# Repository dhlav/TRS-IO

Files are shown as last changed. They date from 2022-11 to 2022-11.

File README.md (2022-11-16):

# TRS-IO

TRS-IO gives a TRS-80 Model 1/III online capabilities and provides
access to a variety of services. TRS-IO currently features the
following capabilities:

1. Access to the <a href="https://retrostore.org">RetroStore</a>
2. <a href="http://frehd.com">FreHD</a> emulation
3. Access to files mounted on a SMB share or located on a micro-SD card
4. Access to remote servers via TCP
5. Virtual printer support

The TRS-IO versions for the Model 1 have some additional features that
are explained below. The following sections give an overview of TRS-IO as well as setup
instructions. This Github repository contains the complete source code
as well as the KiCad schematics for the PCB (Printed Circuit Board).
For the following descriptions it is assumed that an assembled TRS-IO
card is available.

### Overview

The figure below depicts the overall architecture. The TRS-80 machine
is connected to TRS-IO via the I/O Bus.  TRS-IO has a WiFi module that
connects to the local WiFi router. This allows TRS-IO to connect to
the Internet and access various services. Note that TRS-IO can only
connect to a 2.4 GHz WiFi network.



### Prerequisites

TRS-IO requires a TRS-80 Model III with 48kB of RAM or a Model 1 with 16kB of RAM.
Floppy disk drives or a cassette tape are not required.

### Feature list

TRS-IO support
TRS-IO comes in three different versions:

* TRS-IO for the Model III
* TRS-IO for the Model I using a builtin 32kB SRAM
* TRS-IO for the Model I using an FPGA

In the following, each of the versions is explained in detail.

### TRS-IO for the Model III

The following figure shows the top view of the TRS-IO card for the Model III:



1. Power supply via a micro-USB connector
2. Multi-color status LED
3. Status button
4. TRS-80 I/O bus connector
5. Micro-SD card reader
6. Disable FreHD jumper

The TRS-IO card needs to be connected to the TRS-80 Model III's I/O
Bus via a 50-pin ribbon cable (4). Furthermore, the TRS-IO card needs
a separate power supply via a standard 5V USB charger. The micro-USB
connector (1) plugs into the side of the TRS-IO card. The push button
(3) and the multi-color status LED (2) will be explained in the
configuration section.

### TRS-IO for the Model 1 (SRAM edition)

The following figure shows the top view of the TRS-IO card for the Model 1:



1. Power supply via a micro-USB connector
2. Multi-color status LED
3. Status button
4. TRS-80 I/O bus connector
5. Micro-SD card reader

The TRS-IO version for the Model 1 is almost identical to the Model III.
One difference is the I/O bus connector (4) is compatible with the 40-pin
expansion interface of the Model 1. There are several additional features
for the Model 1 version that are not relevant to the Model III version:

* A 32kB SRAM chip for a total of 48kB of total RAM.
* 25ms heartbeat timer to trigger the realtime clock.
* FreHD auto-boot for an unmodified M1.

### TRS-IO for the Model 1 (FPGA edition)

The TRS-IO project features a second version for the Model 1 that makes use
of an FGPA (Field Programmable Gate Array). Using an FPGA allows for some
advanced features not possible with the SRAM edition of TRS-IO. The following
figure shows the top view of the FPGA version for the Model 1:



1. Power supply via a micro-USB connector
2. Multi-color status LED
3. Status button
4. TRS-80 I/O bus connector
5. Micro-SD card reader
6. N/A
7. VGA connector
8. A15/VU configuration jumpers

This version of TRS-IO offers all the features of the SRAM edition of TRS-IO
as outlined in the previous section. Additionally, the FPGA edition also
offers a VGA connector (7) that can be used instead of a CRT monitor. This version
of TRS-IO also emlates the LE18 graphics cards. The color of the VGA signal can
be set to white (X=0), green (X=1), and amber (X=2) via the following OUT statements:

```OUT 31,0:OUT 31,5:OUT 31,X```

There are two configuation jumpers (8):
With the VU jumper, the ESP also powers the FPGA. When using this jumper, the FPGA
SHOULD NOT be powered via its own micro-USB connector; power should only be supplied
to the ESP's micro-USB connector (1). The A15 jumper regulates
the address range the FPGA responds to. Without the A15 jumper, the FPGA only
responds to memory read/write requests for the upper 32 kB (essentially mimicking the
upper RAM of the SRAM edition). With the A15 jumper, the FPGA will respond to the
complete 64kB address space of the Z80. This requires a modified Model 1 as the FPGA also
responds to ROM read requests.

### Configuring TRS-IO

The core of the TRS-IO card is an ESP32 microcontroller that features
a WiFi module that is used to connect to a WiFi router. After
physically connecting the TRS-IO card to a TRS-80 Model 1/III as
explained in the previous sections, the WiFi module on the ESP32
microcontroller first needs to be be configured with the credentials
of the local WiFi network.

While in setup mode, the TRS-IO's status LED will continuously blink
in white to indicate that it has not yet been configured. While in
that mode, TRS-IO will create an open access point called
"TRS-IO". Use a laptop to connect to this WiFi network and then use a
browser to visit URL <a
href="http://trs-io.local">trs-io.local</a>. The following web page
should appear in the browser:

<img src="doc/trs-io-web-ui.png" width="50%" />

Some hosts do not correctly handle mDNS that is used to resolve <a
href="http://trs-io.local">trs-io.local</a>. In that case, visit the
IP address <a href="http://192.168.4.1">192.168.4.1</a> instead.
The web interface shown above can be used to configure SSID and password of the WiFi
network that TRS-IO should connect to, the local timezone as well as
the credentials of a SMB share. For open networks leave the WiFi
password field empty. Note that TRS-IO cannot connect to WiFi networks
that use a capture portal. The timezone as well as the SMB share are
not required but will result in limited functionality.

Once all the information is provided, click on submit to upload the
parameters. TRS-IO will automatically reboot and try to connect to the
specified WiFi network. If successful, the LED will turn green for a
few seconds. If the credentials are wrong or if the specified WiFi
network is not accessible, the LED light will turn permanently red.

Note that TRS-IO will store all parameters in its local flash memory,
so the setup only needs to be performed once. Once TRS-IO is connected
to a WiFi router, it should still be possible to access URL <a
href="http://trs-io.local">trs-io.local</a> from a browser on the same
WiFi network. If mDNS is not supported by the host, the following BASIC
program can be used to determine TRS-IO's local IP address that was
assigned by the router:

```
10 OUT 236,16
20 OUT31,0:OUT31,4
30 C=INP(31):IF C=0 THEN END
40 PRINT CHR$(C);
50 GOTO 30
```

The web interface will also display two icons to indicate the status
of the SMB share and the micro-SD card (see screenshot above). Green
icons indicate that TRS-IO has access. Red icons indicate an error.
In that case, hovering the mouse over the red icon will display the
error message. It should be noted that TRS-IO needs to be rebooted
whenever a micro-SD card is inserted or ejected.

Pushing the status button will make the LED flash twice. The first time for
the WiFi status (green: WiFi connected; red: WiFi not connected) and a
second time for the SMB status (green: connected to SMB share; red:
not connected to SMB share). With proper configuration parameters, the
LED should flash green twice. Holding down the push button for more
than three seconds will erase all configuration parameters and place
TRS-IO back into setup mode (status LED flashing white). This
might be necessary if TRS-IO is moved to a different WiFi network.

The status LED indicates the state of TRS-IO:

* Blinking white: TRS-IO is not configured. It will create an open WiFi access point named "TRS-IO"
* Solid green: when TRS-IO has been configured with WiFi credentials and TRS-IO was able
  to connect to the WiFi network, the status LED will light in solid green for several seconds.
* Solid red: TRS-IO was configured with WiFi credentials but it was not possible to connect to the specified
  network. The reason could be wrong credentials or the specified network is itself offline. The push button can be
  used to reset TRS-IO into setup mode in case different credentials need to be provided.
* Solid blue: TRS-IO performs an OTA (Over-the-Air) update. TRS-IO will automatically detect
  newer firmware versions and will download and install the new firmware. The status LED will light solid blue during
  this process.
* Off: the status LED will be off during regular operations when TRS-IO is connected to the specified
  WiFi network and ready to accept commands from the TRS-80 Model III.
 
### FreHD

TRS-IO is compatible with the popular <a
href="http://frehd.com">FreHD</a> hard disk emulator. The FreHD disk
images can either be stored on a SMB share or on a micro-SD card.
If a micro-SD card is inserted, it will take precedence over
a mounted SMB share. Once TRS-IO is configured to access a SMB share,
simply copy the required files such as <a
href="http://members.iinet.net.au/~ianmav/trs80/downloads.htm">FREHD.ROM</a>
to the SMB share. Alternatively, the disk images can be transferred
to the micro-SD card. The IMPORT/EXPORT utilities will access files on the
SMB share or micro-SD card respectively.

### Virtual Printer Interface

TRS-IO support a virtual printer interface. Visiting <a
href="http://trs-io.local/printer">trs-io.local/printer</a> from a browser
will open the printer interface. Any printer output from the M1/MIII will
be displayed in the printer interface. If the host cannot resolve the mDNS name
trs-io.local, the above BASIC program can be used to determine the TRS-80's
IP address.

 ### Launching the native RetroStore Client

The <a href="https://retrostore.org">RetroStore</a> hosts applications
for the Tandy Radio Shack vintage computers and allows to seamlessly
download and run these applications without the need of cassettes or
floppy disks. TRS-IO acts as a gateway to the <a
href="https://retrostore.org">RetroStore</a>. This requires to run a
program on the TRS-80 that interfaces with TRS-IO. This program is
available as a regular <a
href="https://github.com/apuder/TRS-IO/blob/master/src/esp/components/retrostore/rsclient.cmd">CMD</a>
executable.  For TRS-80 machines with attached physical floppy disks,
this CMD executable can be copied to a floppy disk and launched the
usual way. For TRS-80 machines that have neither floppy disk drives
nor cassette drives, it is also possible to bootstrap the native
client via the following short BASIC program:
 
 ```BASIC
 10 OUT236,16
 20 OUT31,3
 30 OUT31,1
 40 N=INP(31)+256*INP(31)
 50 FOR X=1 TO N:POKE20735+X,INP(31):NEXT
 RUN
 SYSTEM
 *? /20736
 ```
 
The above BASIC program will download the CMD executable from TRS-IO
and launch the native client.  Note that this procedure needs to be
repeated every time the TRS-80 is turned on.
 
### Using the native RetroStore Client

After successfully launching the native RetroStore client, the monitor
of the TRS-80 should look like this:
 

 
The screenshot above shows the main menu of the native RetroStore
client. The arrow indicates the currently selected menu item.  The up
and down cursor keys can be used to move between the various menu
items. Hitting the ENTER key will activate the currently selected
menu item. Pressing CLEAR or BREAK in sub-menus will return to the
previous menu.
 
Keyboard controls:
 
 * Cursor up/down: toggle menu selection
 * ENTER: select current menu selection
 * BREAK/CLEAR: exit to previous screen

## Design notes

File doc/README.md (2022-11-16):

### TRS-IO Documentation

[TCP/IP](tcp_ip.md) - details about the tsrnic TCP/IP API implemented by TRS-IO

[BOM](build.md) - a detailed list of all components you need to build a TRS-IO board

[Old Board Fix](rs_fix.md) - bodge wire updates to make the original RS board compatible with TRS-IO

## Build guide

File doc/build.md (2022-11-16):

#### TRS-IO - Circuit Board Bill of Materials

|Qty|Ref|Digikey Part#|Manuf Part #|Description|
|:---|:---|:---|:---|:---|
|1|U1||ESP32 MODULE|Refer to Supported ESP32 Modules
|1|U3|[ATF16V8B-15PU-ND](https://www.digikey.com/product-detail/en/microchip-technology/ATF16V8B-15PU/ATF16V8B-15PU-ND/1118926)|ATF16V8B-15PU|IC PLD 8MC 15NS 20DIP
|2|U2,U4|[296-8503-5-ND](https://www.digikey.com/product-detail/en/texas-instruments/SN74LVC245AN/296-8503-5-ND/377483)|SN74LVC245AN|IC TXRX NON-INVERT 3.6V 20DIP
|3|Q1,Q2,Q3|[2N7000-G-ND](https://www.digikey.com/product-detail/en/microchip-technology/2N7000-G/2N7000-G-ND/4902350)|2N7000-G|MOSFET N-CH 60V 0.2A TO92-3
|1|D1|[1830-1014-ND](https://www.digikey.com/product-detail/en/inolux/HV-5RGB60/1830-1014-ND/7604616)|HV-5RGB60|LED RGB DIFFUSED 5MM T/H
|1|SW1|[450-1650-ND](https://www.digikey.com/product-detail/en/te-connectivity-alcoswitch-switches/1825910-6/450-1650-ND/1632536)|1825910-6|SWITCH TACTILE SPST-NO 0.05A 24V
|1|SW2||1825910-6|SWITCH TACTILE RIGHT-ANGLE SPST-NO 0.05A 24V
|3|U2,U3,U4|[ED3054-5-ND](https://www.digikey.com/product-detail/en/on-shore-technology-inc/ED20DT/ED3054-5-ND/4147598)|ED20DT|CONN IC DIP SOCKET 20POS TIN
|1|J1|[ED10530-ND](https://www.digikey.com/product-detail/en/on-shore-technology-inc/302-S501/ED10530-ND/2794241)|302-S501|CONN HEADER VERT 50POS 2.54MM
|1||[HDR100IMP40F-G-V-TH-ND](https://www.digikey.com/product-detail/en/chip-quik-inc/HDR100IMP40F-G-V-TH/HDR100IMP40F-G-V-TH-ND/5978200)|HDR100IMP40F-G-V-TH|SIL HDR 40POS 0.1 GOLD PCB
|4|C1,C2,C3,C4|[490-8809-ND](https://www.digikey.com/short/pvj15w)|RDER71E104K0P1H03B|CAP CER 0.1UF 25V X7R RADIAL
|3|R1,R2,R3|||100R 0.25W
|1|R4|||4K7 0.25W

#### Supported ESP32 Modules:
The TRS-IO board supports two commonly available ESP32 modules.

* 38 Pin Module commonly branded as NodeMCU or HiLetGo



* 30 Pin Module commonly branded as DEVKITV1



The pinout and spacing of the two modules differs.  Unless you plan to test your board with both modules, install 15 pin SIL sockets in 1st and 3rd positons for the 30 Pin Module or 19 pin SIL sockets in the 2nd and 4th positions for the 38 Pin Module.

Correct orientation of the modules is shown below:

* 38 Pin Module commonly branded as NodeMCU or HiLetGo



* 30 Pin Module commonly branded as DEVKITV1



#### Notes:
* The switch can be installed in either SW1 or SW2.  SW2 is recommended when assembling the board for installation in a case.
* The LED can be installed in either D1 or J4.  J4 is recommended when assembling the board for installation in a case.  Do not install an LED in both D1 and J4.
* R1,R2 and R3 are current limiting resistors for the LED.  The values are not critical and may require adjustment for some LED.
* The J5 header can be installed and jumpered to disable the internal FreHD emulation when an external FreHD is connected to the expansion connector.  J5 can be omitted if an external FreHD is not used.
* R4 is a pullup for the ESP32 FreHD Inhibit signal. This must always be installed even J5 is not.  Value is not critical.  Anything between 4K7 and 10K will work.
* 5V can be connected to J5 as an alternative to powering ESP32 from USB.  This is recommended when assembling the board for installation in a case.

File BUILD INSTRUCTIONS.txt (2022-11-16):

#TRS-IO - Build Instructions
#OS: Debian 11

#Install Prerequisites:
#Packages for Espressif
sudo apt-get -y install git wget flex bison gperf python3 python3-pip python3-setuptools cmake ninja-build ccache libffi-dev libssl-dev dfu-util libusb-1.0-0

#Packages for TRS-IO
sudo apt-get -y install z80asm sdcc sdcc-libraries

# Some Fixes for linking libraries thats needed by TRS-IO
sudo mkdir -p /lib/z80/
sudo ln -s /usr/share/sdcc/lib/z80/z80.lib /lib/z80/z80.lib

#Python3 as default:
sudo apt-get install python3 python3-pip python3-setuptools
sudo ln -s /usr/bin/python3 /usr/bin/python

#ESP-IDF (Blanket Install Everything):
mkdir -p ~/esp
cd ~/esp
git clone -b v4.2 --recursive https://github.com/espressif/esp-idf.git
cd ~/esp/esp-idf
export IDF_GITHUB_ASSETS="dl.espressif.com/github_assets"
./install.sh
. $HOME/esp/esp-idf/export.sh

#CHECK OUT TRS-IO
cd ~/esp
git clone --recursive https://github.com/dhlav/TRS-IO.git
cd TRS-IO
make all

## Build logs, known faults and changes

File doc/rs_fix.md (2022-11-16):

### RetroStoreCard Wiring Fix

If you have the original RetroStoreCard it can be made compatible with TRS-IO by adding a number of bodge wires.



The original RetroStoreCard looks like the one above.  If you have one of these, then you need to add the following wire connections to bring it up to spec with TRS-IO.



#### Wire Table

|From |To|
|:---|:---|
|ESP 23| IC3 15
|ESP 24| IC3 13
|ESP 25| IC3 14
|ESP 26| IC3 11
|ESP 27| IC3 12
|IC1 6| IC3 5
|IC1 7| IC3 7
|IC1 8| IC3 8
|IC1 9| IC3 9
|IC1 16| IC3 5

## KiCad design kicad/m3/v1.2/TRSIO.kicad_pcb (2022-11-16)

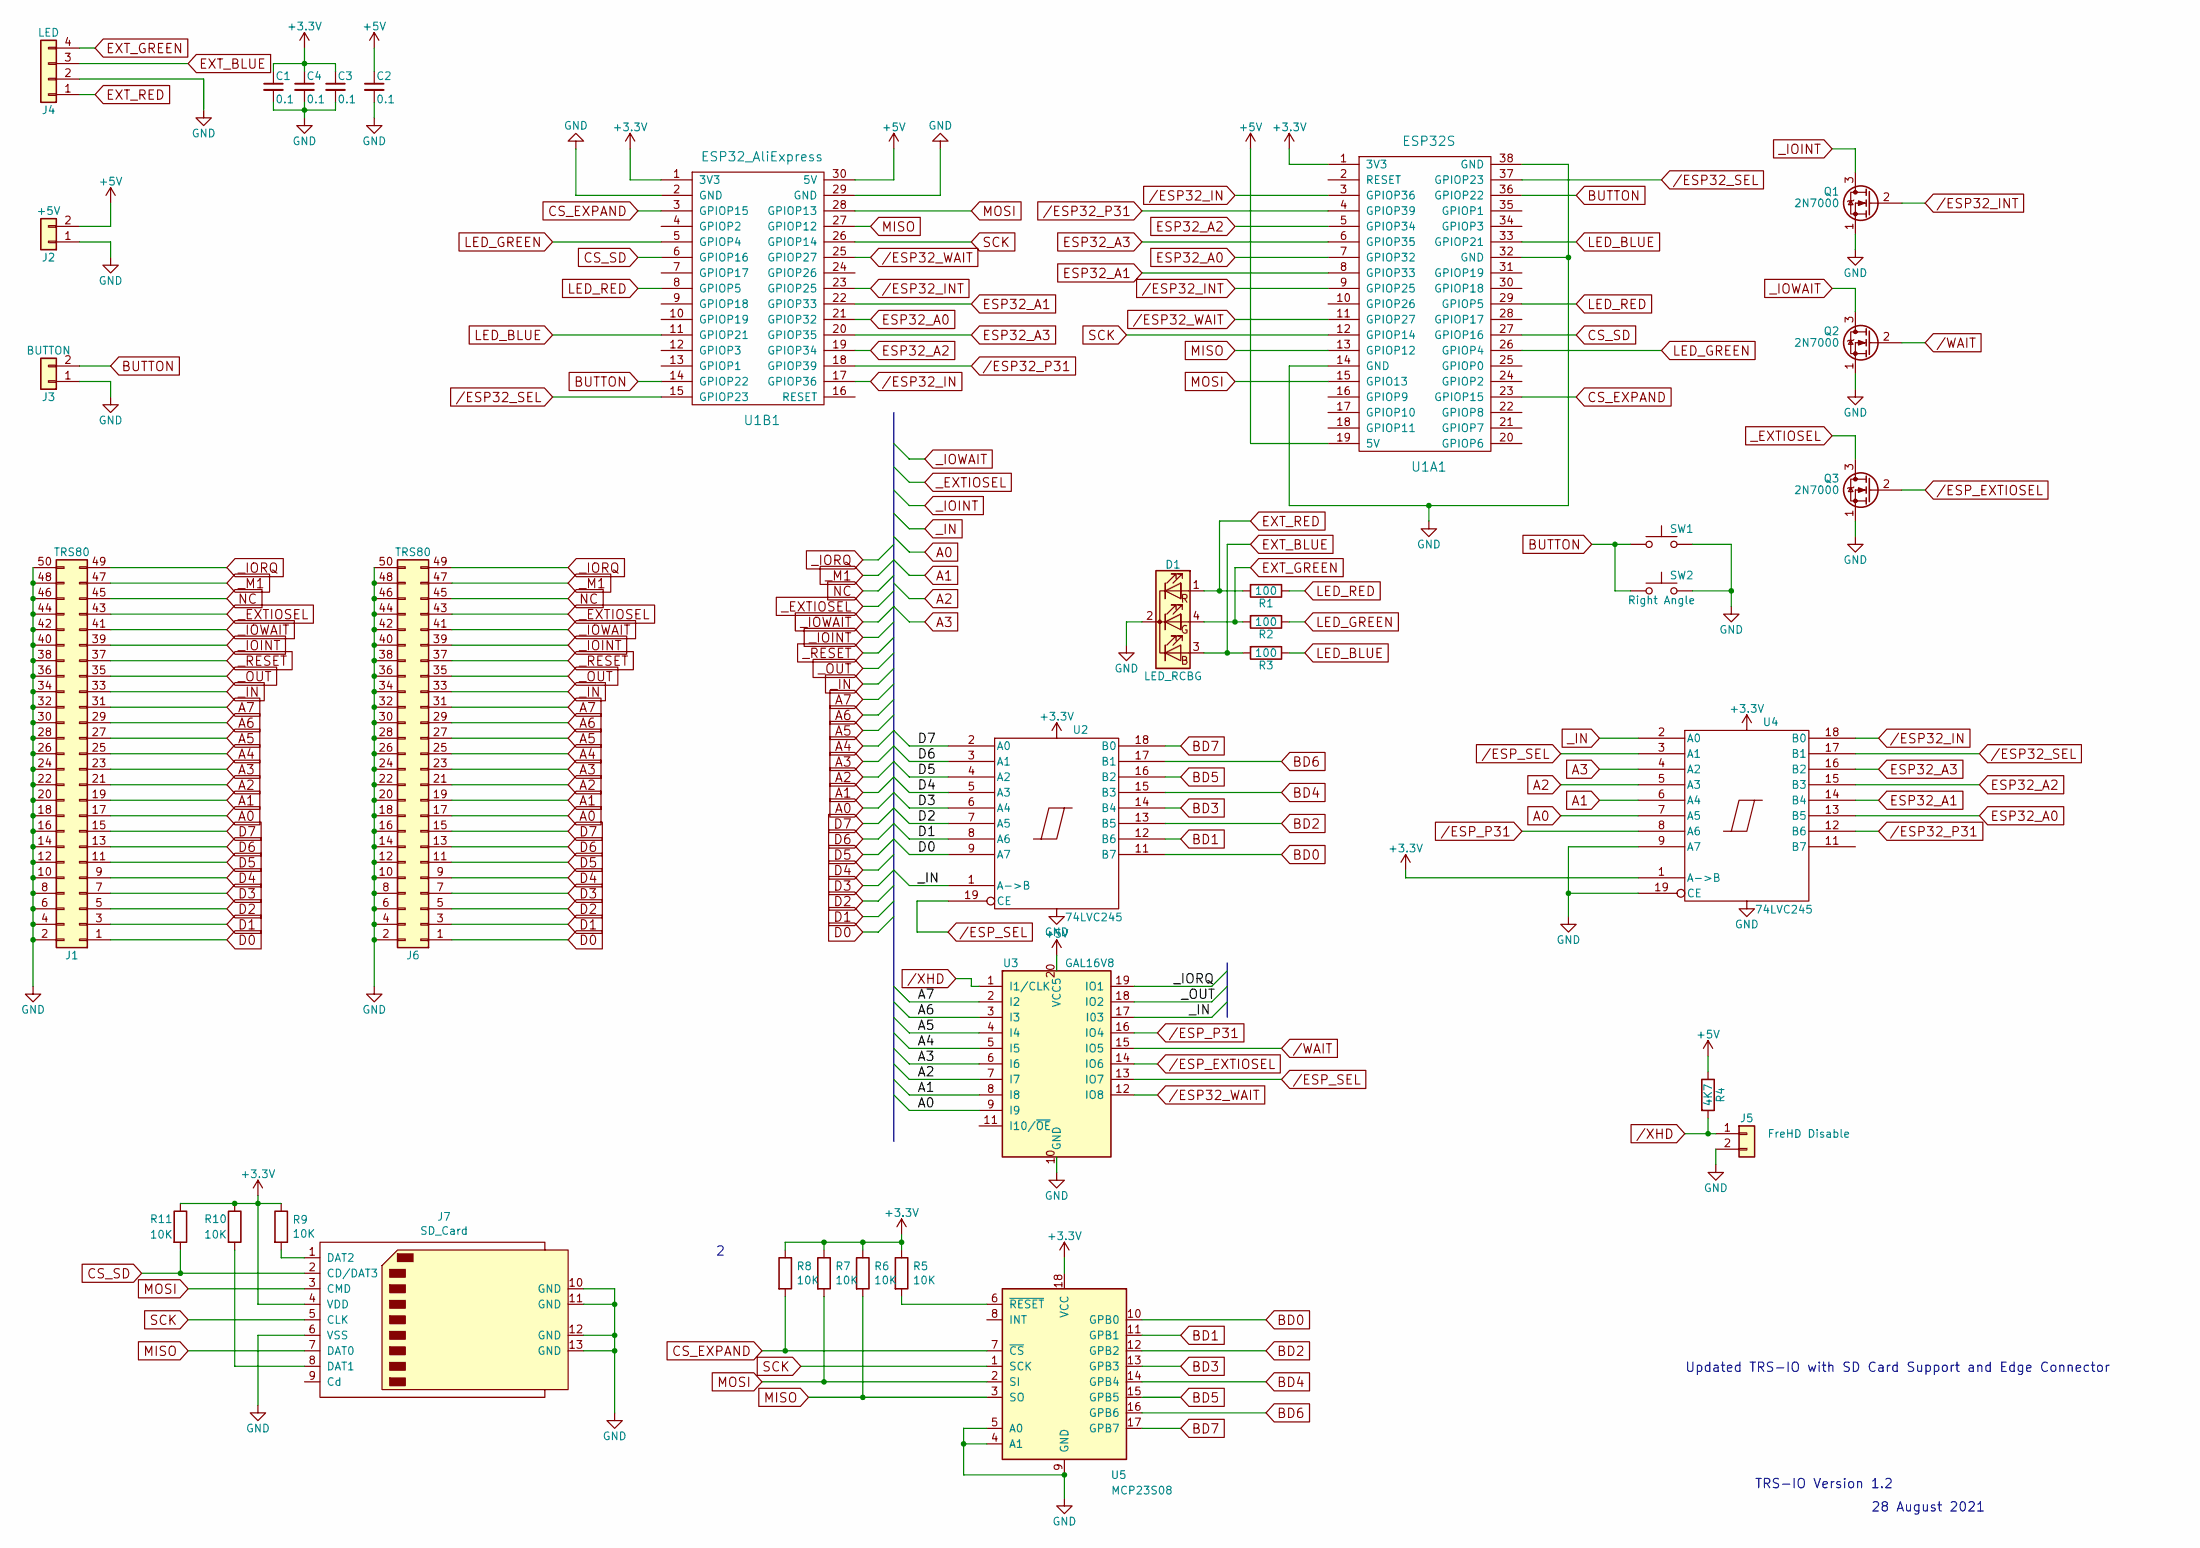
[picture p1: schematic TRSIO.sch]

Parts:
C1, C2, C3, C4: 0.1; C_Disc_D3.0mm_W2.0mm_P2.50mm
D1: LED_RCBG; LED_D5.0mm-4
J1: TRS80; Pin_Header_Straight_2x25_Pitch2.54mm
J2: +5V; Pin_Header_Straight_1x02_Pitch2.54mm
J3: BUTTON; Pin_Header_Straight_1x02_Pitch2.54mm
J4: LED; Pin_Header_Straight_1x04_Pitch2.54mm
J5: FreHD Disable; Pin_Header_Straight_1x02_Pitch2.54mm
J6: TRS80; EDGE50
J7: SD_Card; TFP09-2-12B
Q1, Q2, Q3: 2N7000; TO-92_Molded_Narrow
R1, R2, R3: 100; R_Axial_DIN0207_L6.3mm_D2.5mm_P7.62mm_Horizontal
R4: 4K7; R_Axial_DIN0207_L6.3mm_D2.5mm_P7.62mm_Horizontal
R5, R6, R7, R8, R9, R10, R11: 10K; R_Axial_DIN0207_L6.3mm_D2.5mm_P7.62mm_Horizontal
SW1: SW_Push; SW_PUSH_6mm_h9.5mm
SW2: Right Angle; SW_Tactile_SPST_Angled_PTS645Vx31-2LFS
U1A1: ESP32S; DIP-38_W22.9mm
U1B1: ESP32_AliExpress; DIP-30_W25.4mm
U2, U4: 74LVC245; DIP-20_W7.62mm
U3: GAL16V8; DIP-20_W7.62mm
U5: MCP23S08; DIP-18_W7.62mm

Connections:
+3V3: C1.1, C3.1, C4.1, J7.4 (VDD), R5.1, R6.1, R7.1, R8.1, R9.1, R10.1, R11.1, U1A1.1 (3V3), U1B1.1 (3V3), U2.20 (VCC), U4.1 (A->B), U4.20 (VCC), U5.18 (VCC)
+5V: C2.1, J2.2, R4.1, U1A1.19 (5V), U1B1.30 (5V), U3.20 (VCC5)
/ESP32_IN: U1A1.3 (GPIOP36), U1B1.17 (GPIOP36), U4.18 (B0)
/ESP32_INT: Q1.2 (G), U1A1.9 (GPIOP25), U1B1.23 (GPIOP25)
/ESP32_P31: U1A1.4 (GPIOP39), U1B1.18 (GPIOP39), U4.12 (B6)
/ESP32_SEL: U1A1.37 (GPIOP23), U1B1.15 (GPIOP23), U4.17 (B1)
/ESP32_WAIT: U1A1.11 (GPIOP27), U1B1.25 (GPIOP27), U3.12 (IO8)
/ESP_EXTIOSEL: Q3.2 (G), U3.14 (IO6)
/ESP_P31: U3.16 (IO4), U4.8 (A6)
/ESP_SEL: U2.19 (CE), U3.13 (IO7), U4.3 (A1)
/WAIT: Q2.2 (G), U3.15 (IO5)
/XHD: J5.1, R4.2, U3.1 (I1/CLK)
A0: J1.17, J6.17, U3.9 (I9), U4.7 (A5)
A1: J1.19, J6.19, U3.8 (I8), U4.6 (A4)
A2: J1.21, J6.21, U3.7 (I7), U4.5 (A3)
A3: J1.23, J6.23, U3.6 (I6), U4.4 (A2)
A4: J1.25, J6.25, U3.5 (I5)
A5: J1.27, J6.27, U3.4 (I4)
A6: J1.29, J6.29, U3.3 (I3)
A7: J1.31, J6.31, U3.2 (I2)
BD0: U2.11 (B7), U5.10 (GPB0)
BD1: U2.12 (B6), U5.11 (GPB1)
BD2: U2.13 (B5), U5.12 (GPB2)
BD3: U2.14 (B4), U5.13 (GPB3)
BD4: U2.15 (B3), U5.14 (GPB4)
BD5: U2.16 (B2), U5.15 (GPB5)
BD6: U2.17 (B1), U5.16 (GPB6)
BD7: U2.18 (B0), U5.17 (GPB7)
BUTTON: J3.2, SW1.1, SW2.1, U1A1.36 (GPIOP22), U1B1.14 (GPIOP22)
CS_EXPAND: R8.2, U1A1.23 (GPIOP15), U1B1.3 (GPIOP15), U5.7 (~CS)
CS_SD: J7.2 (CD/DAT3), R11.2, U1A1.27 (GPIOP16), U1B1.6 (GPIOP16)
D0: J1.1, J6.1, U2.9 (A7)
D1: J1.3, J6.3, U2.8 (A6)
D2: J1.5, J6.5, U2.7 (A5)
D3: J1.7, J6.7, U2.6 (A4)
D4: J1.9, J6.9, U2.5 (A3)
D5: J1.11, J6.11, U2.4 (A2)
D6: J1.13, J6.13, U2.3 (A1)
D7: J1.15, J6.15, U2.2 (A0)
ESP32_A0: U1A1.7 (GPIOP32), U1B1.21 (GPIOP32), U4.13 (B5)
ESP32_A1: U1A1.8 (GPIOP33), U1B1.22 (GPIOP33), U4.14 (B4)
ESP32_A2: U1A1.5 (GPIOP34), U1B1.19 (GPIOP34), U4.15 (B3)
ESP32_A3: U1A1.6 (GPIOP35), U1B1.20 (GPIOP35), U4.16 (B2)
EXT_BLUE: D1.3 (BA), J4.3, R3.2
EXT_GREEN: D1.4 (GA), J4.4, R2.2
EXT_RED: D1.1 (RA), J4.1, R1.2
GND: C1.2, C2.2, C3.2, C4.2, D1.2 (K), J1.2, J1.4, J1.6, J1.8, J1.10, J1.12, J1.14, J1.16, J1.18, J1.20, J1.22, J1.24, J1.26, J1.28, J1.30, J1.32, J1.34, J1.36, J1.38, J1.40, J1.42, J1.44, J1.46, J1.48, J1.50, J2.1, J3.1, J4.2, J5.2, J6.2, J6.4, J6.6, J6.8, J6.10, J6.12, J6.14, J6.16, J6.18, J6.20, J6.22, J6.24, J6.26, J6.28, J6.30, J6.32, J6.34, J6.36, J6.38, J6.40, J6.42, J6.44, J6.46, J6.48, J6.50, J7.6 (VSS), J7.10 (GND), J7.11 (GND), J7.12 (GND), J7.13 (GND), Q1.1 (S), Q2.1 (S), Q3.1 (S), SW1.2, SW2.2, U1A1.14 (GND), U1A1.32 (GND), U1A1.38 (GND), U1B1.2 (GND), U1B1.29 (GND), U2.10 (GND), U3.10 (GND), U4.9 (A7), U4.10 (GND), U4.19 (CE), U5.4 (A1), U5.5 (A0), U5.9 (GND)
LED_BLUE: R3.1, U1A1.33 (GPIOP21), U1B1.11 (GPIOP21)
LED_GREEN: R2.1, U1A1.26 (GPIOP4), U1B1.5 (GPIOP4)
LED_RED: R1.1, U1A1.29 (GPIOP5), U1B1.8 (GPIOP5)
MISO: J7.7 (DAT0), R6.2, U1A1.13 (GPIOP12), U1B1.27 (GPIOP12), U5.3 (SO)
MOSI: J7.3 (CMD), R7.2, U1A1.15 (GPIO13), U1B1.28 (GPIOP13), U5.2 (SI)
NC: J1.45, J6.45
unnamed: J7.1 (DAT2), R9.2
unnamed: J7.8 (DAT1), R10.2
unnamed: R5.2, U5.6 (~RESET)
SCK: J7.5 (CLK), U1A1.12 (GPIOP14), U1B1.26 (GPIOP14), U5.1 (SCK)
_EXTIOSEL: J1.43, J6.43, Q3.3 (D)
_IN: J1.33, J6.33, U2.1 (A->B), U3.17 (I03), U4.2 (A0)
_IOINT: J1.39, J6.39, Q1.3 (D)
_IORQ: J1.49, J6.49, U3.19 (IO1)
_IOWAIT: J1.41, J6.41, Q2.3 (D)
_M1: J1.47, J6.47
_OUT: J1.35, J6.35, U3.18 (IO2)
_RESET: J1.37, J6.37

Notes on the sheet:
Updated TRS-IO with SD Card Support and Edge Connector
28 August 2021
TRS-IO Version 1.2

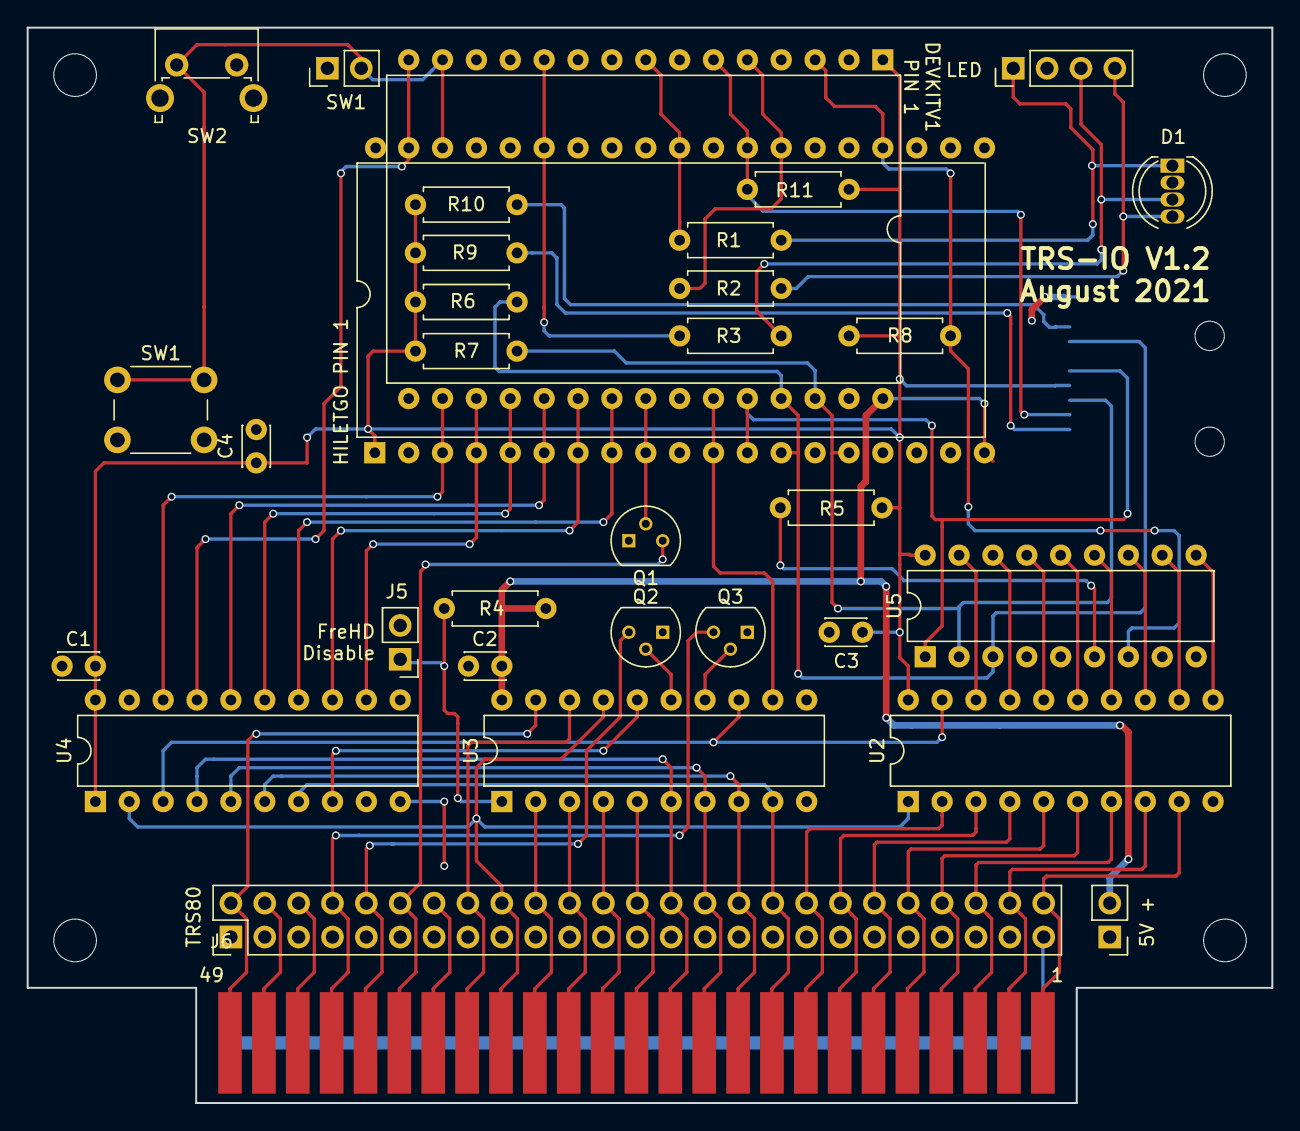
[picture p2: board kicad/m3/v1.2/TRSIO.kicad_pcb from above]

Board: 2 copper layers, 93.3 x 80.6 mm, 34 parts (1 on the bottom side), 65 nets.

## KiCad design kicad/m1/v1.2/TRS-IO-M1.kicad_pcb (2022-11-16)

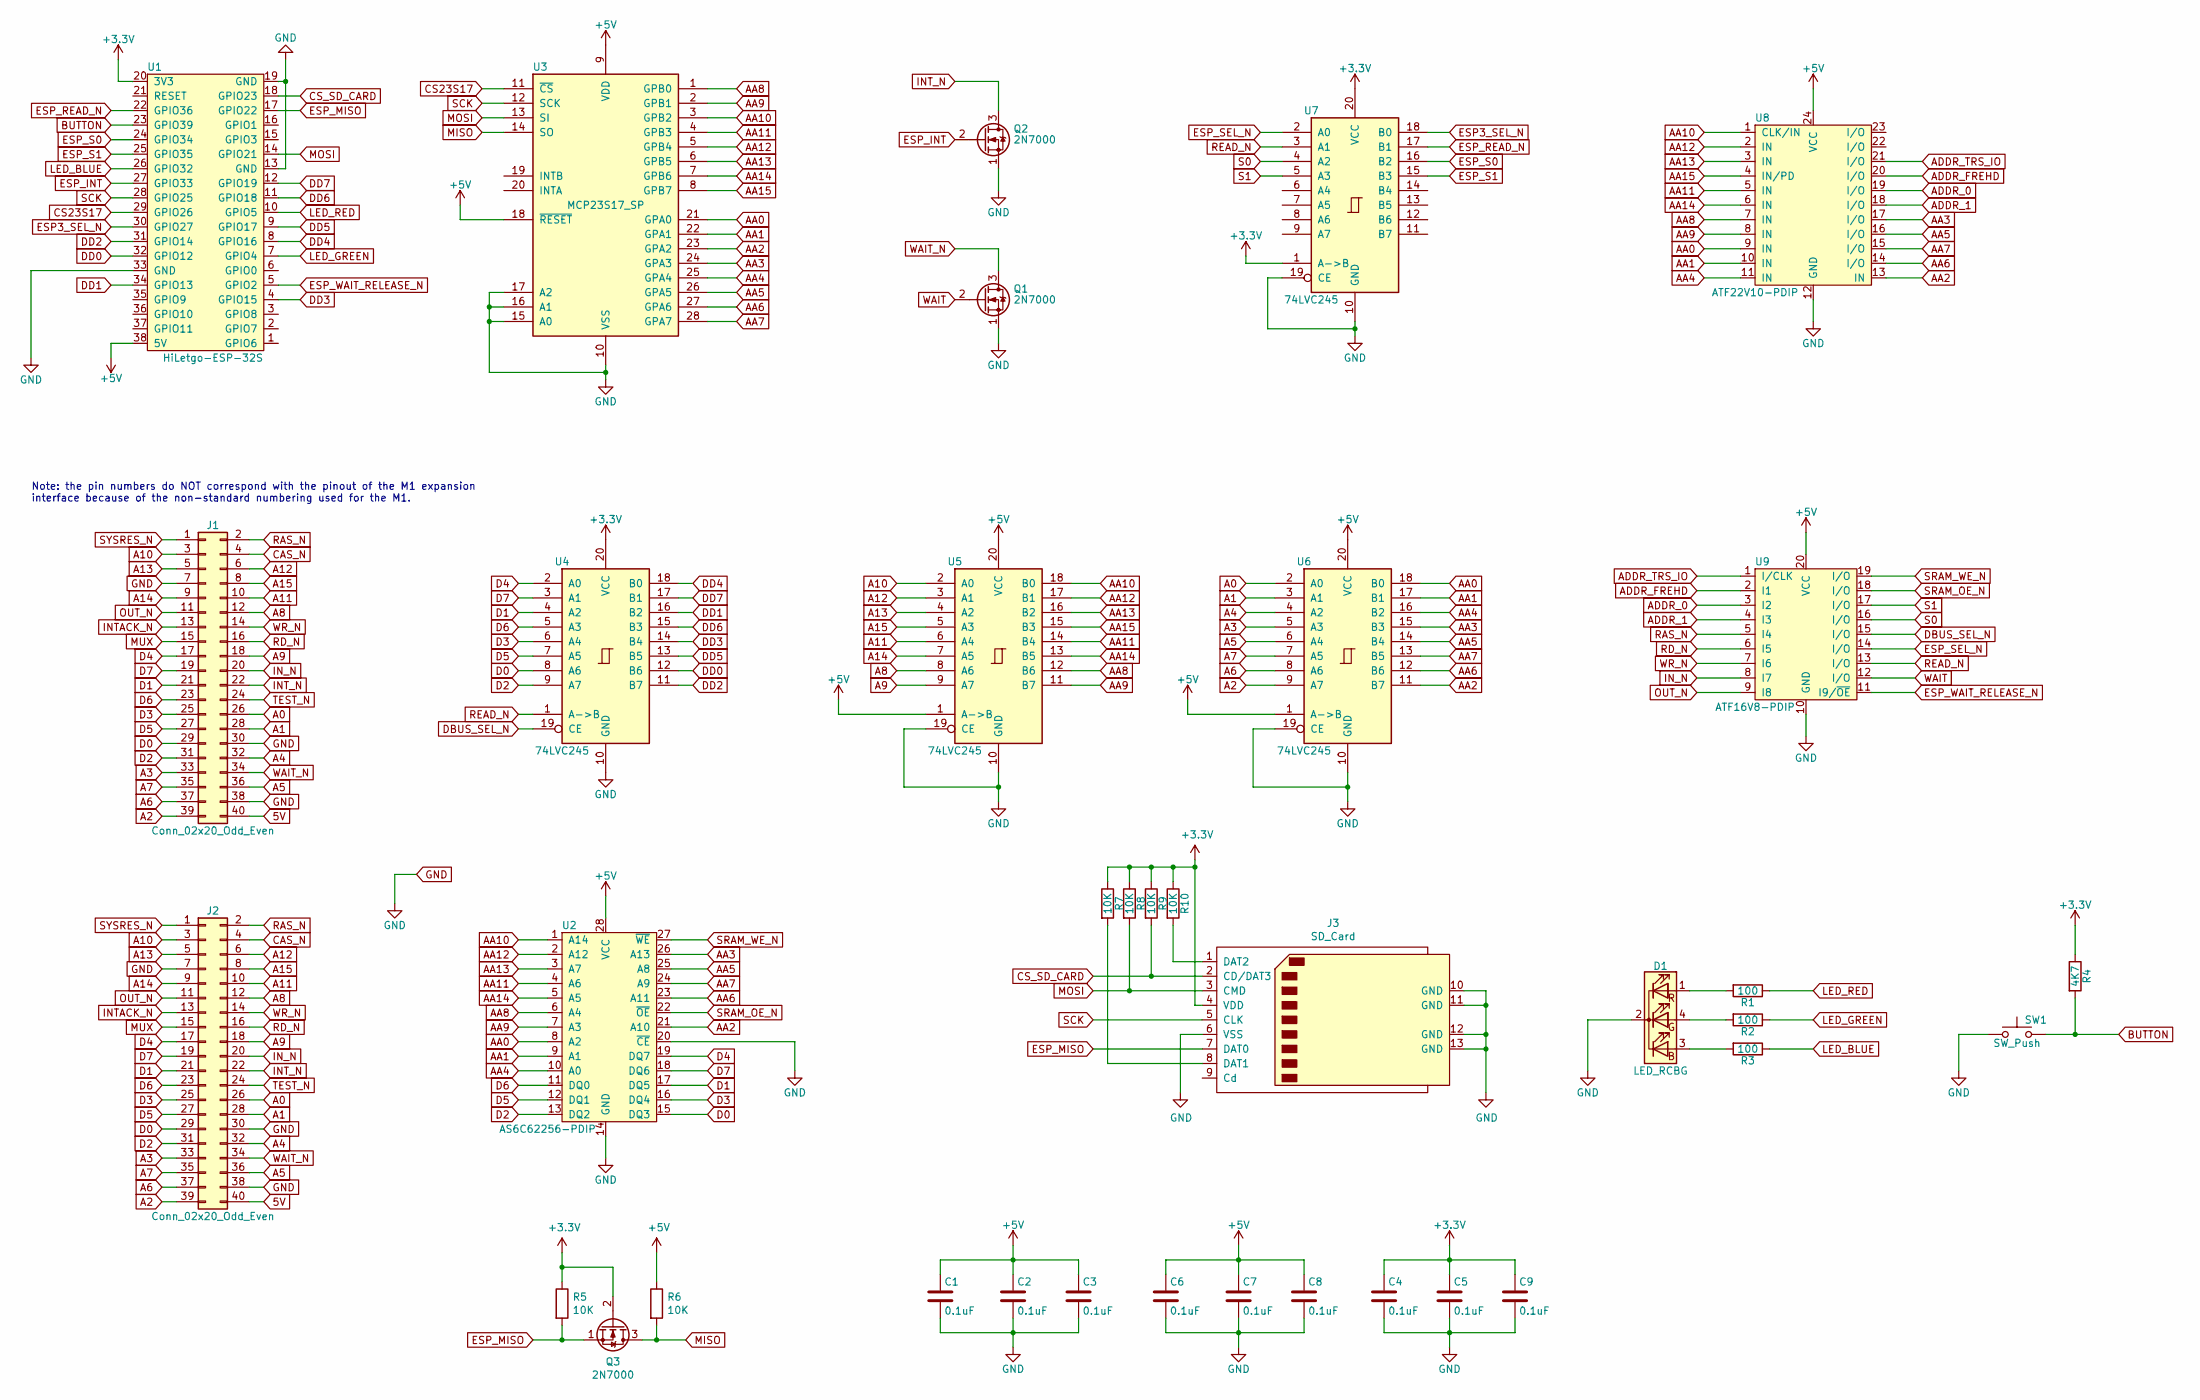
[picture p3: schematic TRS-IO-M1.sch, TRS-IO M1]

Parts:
C1, C2, C3, C4, C5, C6, C7, C8, C9: 0.1uF; C_Disc_D3.0mm_W2.0mm_P2.50mm
D1: LED_RCBG; LED_D5.0mm-4_RGB
J1: Conn_02x20_Odd_Even; PinHeader_2x20_P2.54mm_Vertical
J2: Conn_02x20_Odd_Even; TRSEDGE
J3: SD_Card; TFP09-2-12B
Q1, Q2, Q3: 2N7000; TO-92_Inline
R1, R2, R3: 100; R_Axial_DIN0207_L6.3mm_D2.5mm_P7.62mm_Horizontal
R4: 4K7; R_Axial_DIN0207_L6.3mm_D2.5mm_P7.62mm_Horizontal
R5, R6, R7, R8, R9, R10: 10K; R_Axial_DIN0207_L6.3mm_D2.5mm_P7.62mm_Horizontal
SW1: SW_Push; SW_PUSH_6mm_H9.5mm
U1: HiLetgo-ESP-32S; DIP-38_W22.9mm
U2: AS6C62256-PDIP; DIP-28_W15.24mm
U3: MCP23S17_SP; DIP-28_W7.62mm
U4, U5, U6, U7: 74LVC245; DIP-20_W7.62mm
U8: ATF22V10-PDIP; DIP-24_W7.62mm
U9: ATF16V8-PDIP; DIP-20_W7.62mm

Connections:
5V: J1.40, J2.40
+3V3: C4.1, C5.1, C9.1, J3.4 (VDD), Q3.2 (G), R4.1, R5.1, R7.1, R8.1, R9.1, R10.1, U1.20 (3V3), U4.20 (VCC), U7.1 (A->B), U7.20 (VCC)
+5V: C1.1, C2.1, C3.1, C6.1, C7.1, C8.1, R6.1, U1.38 (5V), U2.28 (VCC), U3.9 (VDD), U3.18 (~RESET~), U5.1 (A->B), U5.20 (VCC), U6.1 (A->B), U6.20 (VCC), U8.24 (VCC), U9.20 (VCC)
A0: J1.26, J2.26, U6.2 (A0)
A1: J1.28, J2.28, U6.3 (A1)
A2: J1.39, J2.39, U6.9 (A7)
A3: J1.33, J2.33, U6.5 (A3)
A4: J1.32, J2.32, U6.4 (A2)
A5: J1.36, J2.36, U6.6 (A4)
A6: J1.37, J2.37, U6.8 (A6)
A7: J1.35, J2.35, U6.7 (A5)
A8: J1.12, J2.12, U5.8 (A6)
A9: J1.18, J2.18, U5.9 (A7)
A10: J1.3, J2.3, U5.2 (A0)
A11: J1.10, J2.10, U5.6 (A4)
A12: J1.6, J2.6, U5.3 (A1)
A13: J1.5, J2.5, U5.4 (A2)
A14: J1.9, J2.9, U5.7 (A5)
A15: J1.8, J2.8, U5.5 (A3)
AA0: U2.8 (A2), U3.21 (GPA0), U6.18 (B0), U8.9 (IN)
AA1: U2.9 (A1), U3.22 (GPA1), U6.17 (B1), U8.10 (IN)
AA2: U2.21 (A10), U3.23 (GPA2), U6.11 (B7), U8.13 (IN)
AA3: U2.26 (A13), U3.24 (GPA3), U6.15 (B3), U8.17 (I/O)
AA4: U2.10 (A0), U3.25 (GPA4), U6.16 (B2), U8.11 (IN)
AA5: U2.25 (A8), U3.26 (GPA5), U6.14 (B4), U8.16 (I/O)
AA6: U2.23 (A11), U3.27 (GPA6), U6.12 (B6), U8.14 (I/O)
AA7: U2.24 (A9), U3.28 (GPA7), U6.13 (B5), U8.15 (I/O)
AA8: U2.6 (A4), U3.1 (GPB0), U5.12 (B6), U8.7 (IN)
AA9: U2.7 (A3), U3.2 (GPB1), U5.11 (B7), U8.8 (IN)
AA10: U2.1 (A14), U3.3 (GPB2), U5.18 (B0), U8.1 (CLK/IN)
AA11: U2.4 (A6), U3.4 (GPB3), U5.14 (B4), U8.5 (IN)
AA12: U2.2 (A12), U3.5 (GPB4), U5.17 (B1), U8.2 (IN)
AA13: U2.3 (A7), U3.6 (GPB5), U5.16 (B2), U8.3 (IN)
AA14: U2.5 (A5), U3.7 (GPB6), U5.13 (B5), U8.6 (IN)
AA15: U3.8 (GPB7), U5.15 (B3), U8.4 (IN/PD)
ADDR_0: U8.19 (I/O), U9.3 (I2)
ADDR_1: U8.18 (I/O), U9.4 (I3)
ADDR_FREHD: U8.20 (I/O), U9.2 (I1)
ADDR_TRS_IO: U8.21 (I/O), U9.1 (I/CLK)
BUTTON: R4.2, SW1.2, U1.23 (GPIO39)
CAS_N: J1.4, J2.4
CS23S17: U1.29 (GPIO26), U3.11 (~CS~)
CS_SD_CARD: J3.2 (CD/DAT3), R9.2, U1.18 (GPIO23)
D0: J1.29, J2.29, U2.15 (DQ3), U4.8 (A6)
D1: J1.21, J2.21, U2.17 (DQ5), U4.4 (A2)
D2: J1.31, J2.31, U2.13 (DQ2), U4.9 (A7)
D3: J1.25, J2.25, U2.16 (DQ4), U4.6 (A4)
D4: J1.17, J2.17, U2.19 (DQ7), U4.2 (A0)
D5: J1.27, J2.27, U2.12 (DQ1), U4.7 (A5)
D6: J1.23, J2.23, U2.11 (DQ0), U4.5 (A3)
D7: J1.19, J2.19, U2.18 (DQ6), U4.3 (A1)
DBUS_SEL_N: U4.19 (CE), U9.15 (I/O)
DD0: U1.32 (GPIO12), U4.12 (B6)
DD1: U1.34 (GPIO13), U4.16 (B2)
DD2: U1.31 (GPIO14), U4.11 (B7)
DD3: U1.4 (GPIO15), U4.14 (B4)
DD4: U1.8 (GPIO16), U4.18 (B0)
DD5: U1.9 (GPIO17), U4.13 (B5)
DD6: U1.11 (GPIO18), U4.15 (B3)
DD7: U1.12 (GPIO19), U4.17 (B1)
ESP3_SEL_N: U1.30 (GPIO27), U7.18 (B0)
ESP_INT: Q2.2 (G), U1.27 (GPIO33)
ESP_MISO: J3.7 (DAT0), Q3.1 (S), R5.2, U1.17 (GPIO22)
ESP_READ_N: U1.22 (GPIO36), U7.17 (B1)
ESP_S0: U1.24 (GPIO34), U7.16 (B2)
ESP_S1: U1.25 (GPIO35), U7.15 (B3)
ESP_SEL_N: U7.2 (A0), U9.14 (I/O)
ESP_WAIT_RELEASE_N: U1.5 (GPIO2), U9.11 (I9/~OE)
GND: C1.2, C2.2, C3.2, C4.2, C5.2, C6.2, C7.2, C8.2, C9.2, D1.2 (K), J1.7, J1.30, J1.38, J2.7, J2.30, J2.38, J3.6 (VSS), J3.10 (GND), J3.11 (GND), J3.12 (GND), J3.13 (GND), Q1.1 (S), Q2.1 (S), SW1.1, U1.13 (GND), U1.19 (GND), U1.33 (GND), U2.14 (GND), U2.20 (~CE), U3.10 (VSS), U3.15 (A0), U3.16 (A1), U3.17 (A2), U4.10 (GND), U5.10 (GND), U5.19 (CE), U6.10 (GND), U6.19 (CE), U7.10 (GND), U7.19 (CE), U8.12 (GND), U9.10 (GND)
INTACK_N: J1.13, J2.13
INT_N: J1.22, J2.22, Q2.3 (D)
IN_N: J1.20, J2.20, U9.8 (I7)
LED_BLUE: R3.1, U1.26 (GPIO32)
LED_GREEN: R2.1, U1.7 (GPIO4)
LED_RED: R1.1, U1.10 (GPIO5)
MISO: Q3.3 (D), R6.2, U3.14 (SO)
MOSI: J3.3 (CMD), R8.2, U1.14 (GPIO21), U3.13 (SI)
MUX: J1.15, J2.15
unnamed: D1.1 (RA), R1.2
unnamed: D1.3 (BA), R3.2
unnamed: D1.4 (GA), R2.2
unnamed: J3.1 (DAT2), R10.2
unnamed: J3.8 (DAT1), R7.2
OUT_N: J1.11, J2.11, U9.9 (I8)
RAS_N: J1.2, J2.2, U9.5 (I4)
RD_N: J1.16, J2.16, U9.6 (I5)
READ_N: U4.1 (A->B), U7.3 (A1), U9.13 (I/O)
S0: U7.4 (A2), U9.16 (I/O)
S1: U7.5 (A3), U9.17 (I/O)
SCK: J3.5 (CLK), U1.28 (GPIO25), U3.12 (SCK)
SRAM_OE_N: U2.22 (~OE), U9.18 (I/O)
SRAM_WE_N: U2.27 (~WE), U9.19 (I/O)
SYSRES_N: J1.1, J2.1
TEST_N: J1.24, J2.24
WAIT: Q1.2 (G), U9.12 (I/O)
WAIT_N: J1.34, J2.34, Q1.3 (D)
WR_N: J1.14, J2.14, U9.7 (I6)

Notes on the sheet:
Note: the pin numbers do NOT correspond with the pinout of the M1 expansion interface because of the non-standard numbering used for the M1.

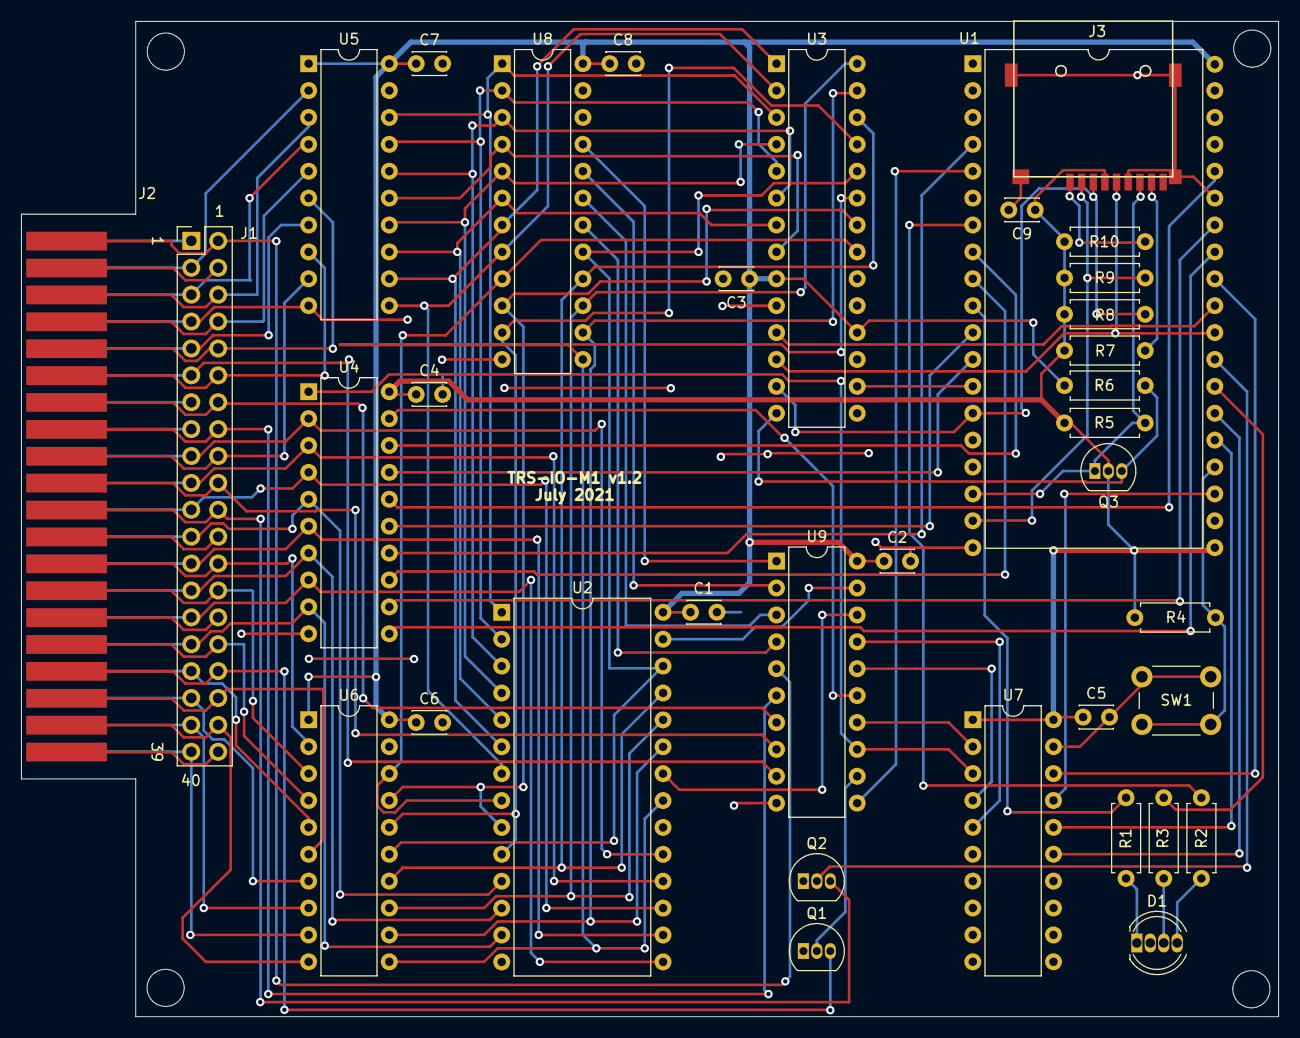
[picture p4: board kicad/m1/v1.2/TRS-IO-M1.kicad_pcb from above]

Board: 2 copper layers, 118.7 x 94.0 mm, 36 parts (0 on the bottom side), 97 nets.

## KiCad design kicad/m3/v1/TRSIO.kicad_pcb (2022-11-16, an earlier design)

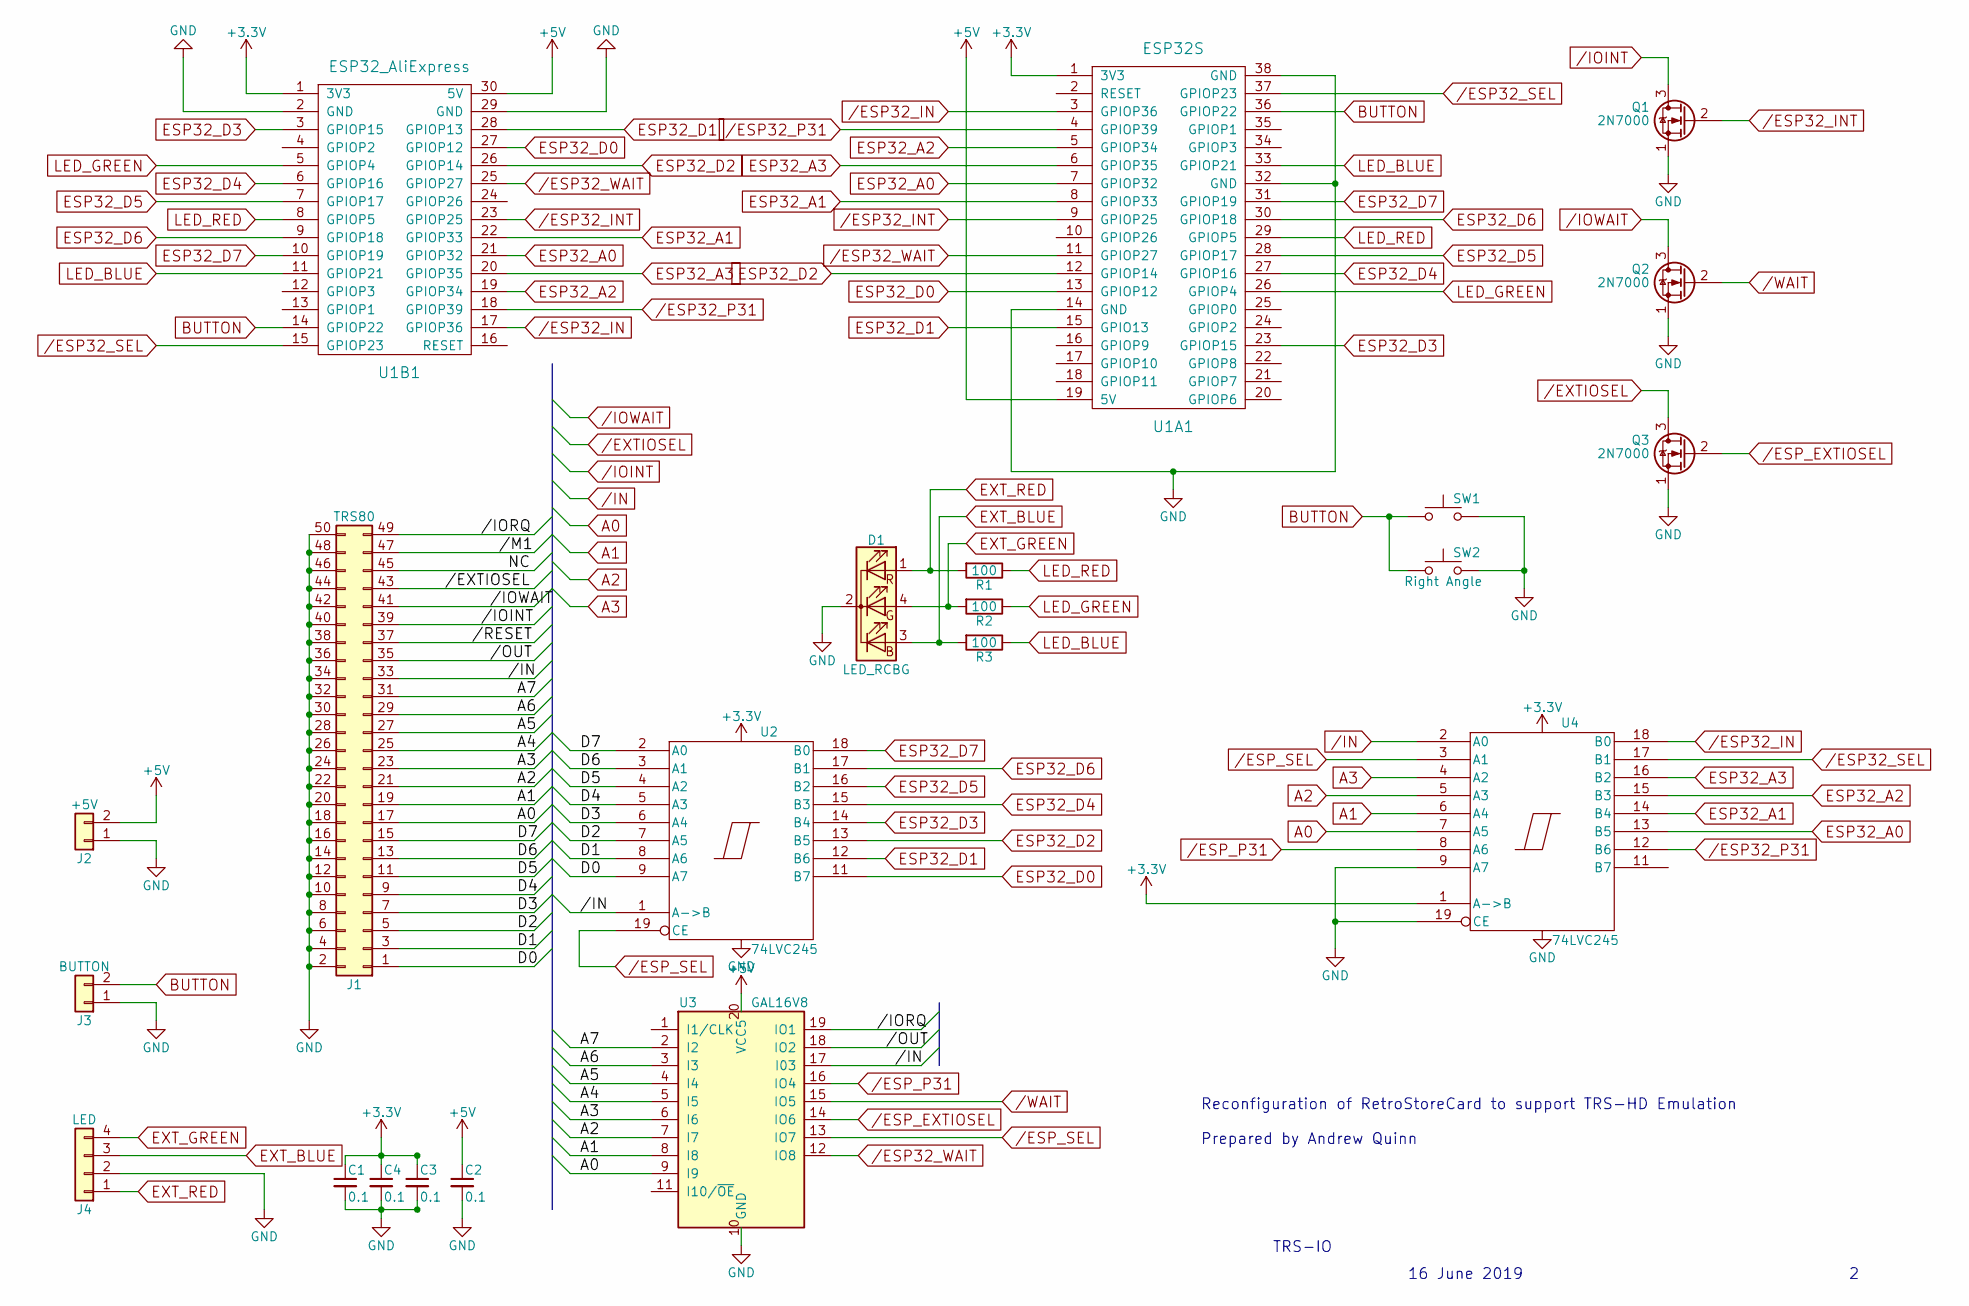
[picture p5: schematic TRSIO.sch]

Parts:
C1, C2, C3, C4: 0.1; C_Disc_D3.0mm_W2.0mm_P2.50mm
D1: LED_RCBG; LED_D5.0mm-4
J1: TRS80; Pin_Header_Straight_2x25_Pitch2.54mm
J2: +5V; Pin_Header_Straight_1x02_Pitch2.54mm
J3: BUTTON; Pin_Header_Straight_1x02_Pitch2.54mm
J4: LED; Pin_Header_Straight_1x04_Pitch2.54mm
Q1, Q2, Q3: 2N7000; TO-92_Molded_Narrow
R1, R2, R3: 100; R_Axial_DIN0207_L6.3mm_D2.5mm_P7.62mm_Horizontal
SW1: SW_Push; SW_PUSH_6mm_h9.5mm
SW2: Right Angle; SW_Tactile_SPST_Angled_PTS645Vx31-2LFS
U1A1: ESP32S; DIP-38_W22.9mm
U1B1: ESP32_AliExpress; DIP-30_W25.4mm
U2, U4: 74LVC245; DIP-20_W7.62mm
U3: GAL16V8; DIP-20_W7.62mm

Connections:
+3V3: C1.1, C3.1, C4.1, U1A1.1 (3V3), U1B1.1 (3V3), U2.20 (VCC), U4.1 (A->B), U4.20 (VCC)
+5V: C2.1, J2.2, U1A1.19 (5V), U1B1.30 (5V), U3.20 (VCC5)
//IORQ: J1.49, U3.19 (IO1)
//OUT: J1.35, U3.18 (IO2)
/A4: J1.25, U3.5 (I5)
/A5: J1.27, U3.4 (I4)
/A6: J1.29, U3.3 (I3)
/A7: J1.31, U3.2 (I2)
/D0: J1.1, U2.9 (A7)
/D1: J1.3, U2.8 (A6)
/D2: J1.5, U2.7 (A5)
/D3: J1.7, U2.6 (A4)
/D4: J1.9, U2.5 (A3)
/D5: J1.11, U2.4 (A2)
/D6: J1.13, U2.3 (A1)
/D7: J1.15, U2.2 (A0)
/ESP32_IN: U1A1.3 (GPIOP36), U1B1.17 (GPIOP36), U4.18 (B0)
/ESP32_INT: Q1.2 (G), U1A1.9 (GPIOP25), U1B1.23 (GPIOP25)
/ESP32_P31: U1A1.4 (GPIOP39), U1B1.18 (GPIOP39), U4.12 (B6)
/ESP32_SEL: U1A1.37 (GPIOP23), U1B1.15 (GPIOP23), U4.17 (B1)
/ESP32_WAIT: U1A1.11 (GPIOP27), U1B1.25 (GPIOP27), U3.12 (IO8)
/ESP_EXTIOSEL: Q3.2 (G), U3.14 (IO6)
/ESP_P31: U3.16 (IO4), U4.8 (A6)
/ESP_SEL: U2.19 (CE), U3.13 (IO7), U4.3 (A1)
/EXTIOSEL: J1.43, Q3.3 (D)
/IN: J1.33, U2.1 (A->B), U3.17 (I03), U4.2 (A0)
/IOINT: J1.39, Q1.3 (D)
/IOWAIT: J1.41, Q2.3 (D)
/WAIT: Q2.2 (G), U3.15 (IO5)
A0: J1.17, U3.9 (I9), U4.7 (A5)
A1: J1.19, U3.8 (I8), U4.6 (A4)
A2: J1.21, U3.7 (I7), U4.5 (A3)
A3: J1.23, U3.6 (I6), U4.4 (A2)
BUTTON: J3.2, SW1.1, SW2.1, U1A1.36 (GPIOP22), U1B1.14 (GPIOP22)
ESP32_A0: U1A1.7 (GPIOP32), U1B1.21 (GPIOP32), U4.13 (B5)
ESP32_A1: U1A1.8 (GPIOP33), U1B1.22 (GPIOP33), U4.14 (B4)
ESP32_A2: U1A1.5 (GPIOP34), U1B1.19 (GPIOP34), U4.15 (B3)
ESP32_A3: U1A1.6 (GPIOP35), U1B1.20 (GPIOP35), U4.16 (B2)
ESP32_D0: U1A1.13 (GPIOP12), U1B1.27 (GPIOP12), U2.11 (B7)
ESP32_D1: U1A1.15 (GPIO13), U1B1.28 (GPIOP13), U2.12 (B6)
ESP32_D2: U1A1.12 (GPIOP14), U1B1.26 (GPIOP14), U2.13 (B5)
ESP32_D3: U1A1.23 (GPIOP15), U1B1.3 (GPIOP15), U2.14 (B4)
ESP32_D4: U1A1.27 (GPIOP16), U1B1.6 (GPIOP16), U2.15 (B3)
ESP32_D5: U1A1.28 (GPIOP17), U1B1.7 (GPIOP17), U2.16 (B2)
ESP32_D6: U1A1.30 (GPIOP18), U1B1.9 (GPIOP18), U2.17 (B1)
ESP32_D7: U1A1.31 (GPIOP19), U1B1.10 (GPIOP19), U2.18 (B0)
EXT_BLUE: D1.3 (BA), J4.3, R3.2
EXT_GREEN: D1.4 (GA), J4.4, R2.2
EXT_RED: D1.1 (RA), J4.1, R1.2
GND: C1.2, C2.2, C3.2, C4.2, D1.2 (K), J1.2, J1.4, J1.6, J1.8, J1.10, J1.12, J1.14, J1.16, J1.18, J1.20, J1.22, J1.24, J1.26, J1.28, J1.30, J1.32, J1.34, J1.36, J1.38, J1.40, J1.42, J1.44, J1.46, J1.48, J1.50, J2.1, J3.1, J4.2, Q1.1 (S), Q2.1 (S), Q3.1 (S), SW1.2, SW2.2, U1A1.14 (GND), U1A1.32 (GND), U1A1.38 (GND), U1B1.2 (GND), U1B1.29 (GND), U2.10 (GND), U3.10 (GND), U4.9 (A7), U4.10 (GND), U4.19 (CE)
LED_BLUE: R3.1, U1A1.33 (GPIOP21), U1B1.11 (GPIOP21)
LED_GREEN: R2.1, U1A1.26 (GPIOP4), U1B1.5 (GPIOP4)
LED_RED: R1.1, U1A1.29 (GPIOP5), U1B1.8 (GPIOP5)

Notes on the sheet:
Reconfiguration of RetroStoreCard to support TRS-HD Emulation Prepared by Andrew Quinn
16 June 2019
TRS-IO

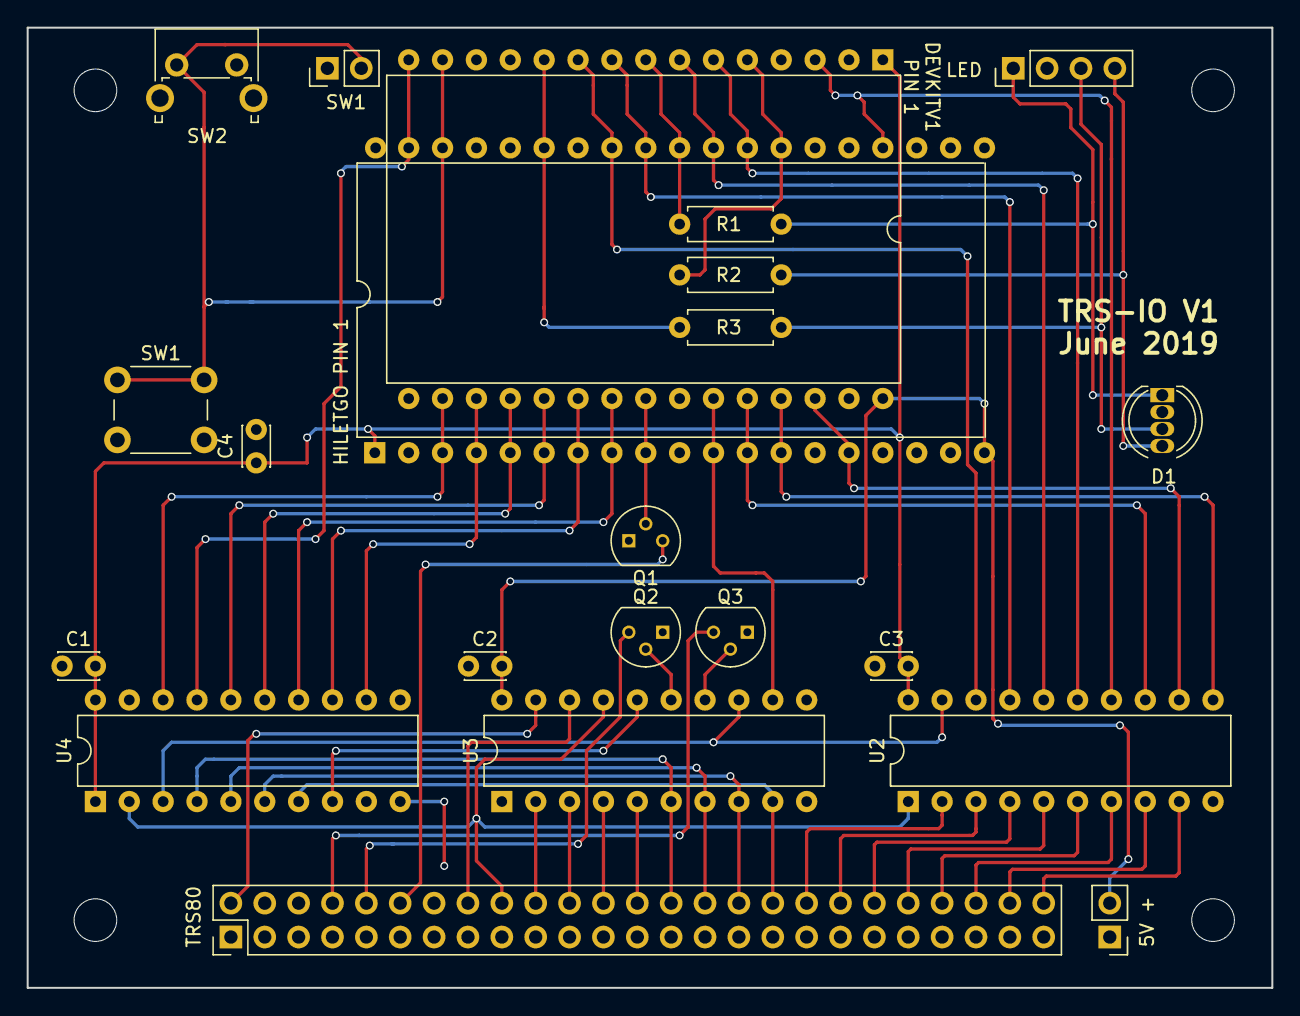
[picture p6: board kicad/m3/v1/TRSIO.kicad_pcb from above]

Board: 2 copper layers, 93.3 x 72.0 mm, 22 parts (0 on the bottom side), 53 nets.

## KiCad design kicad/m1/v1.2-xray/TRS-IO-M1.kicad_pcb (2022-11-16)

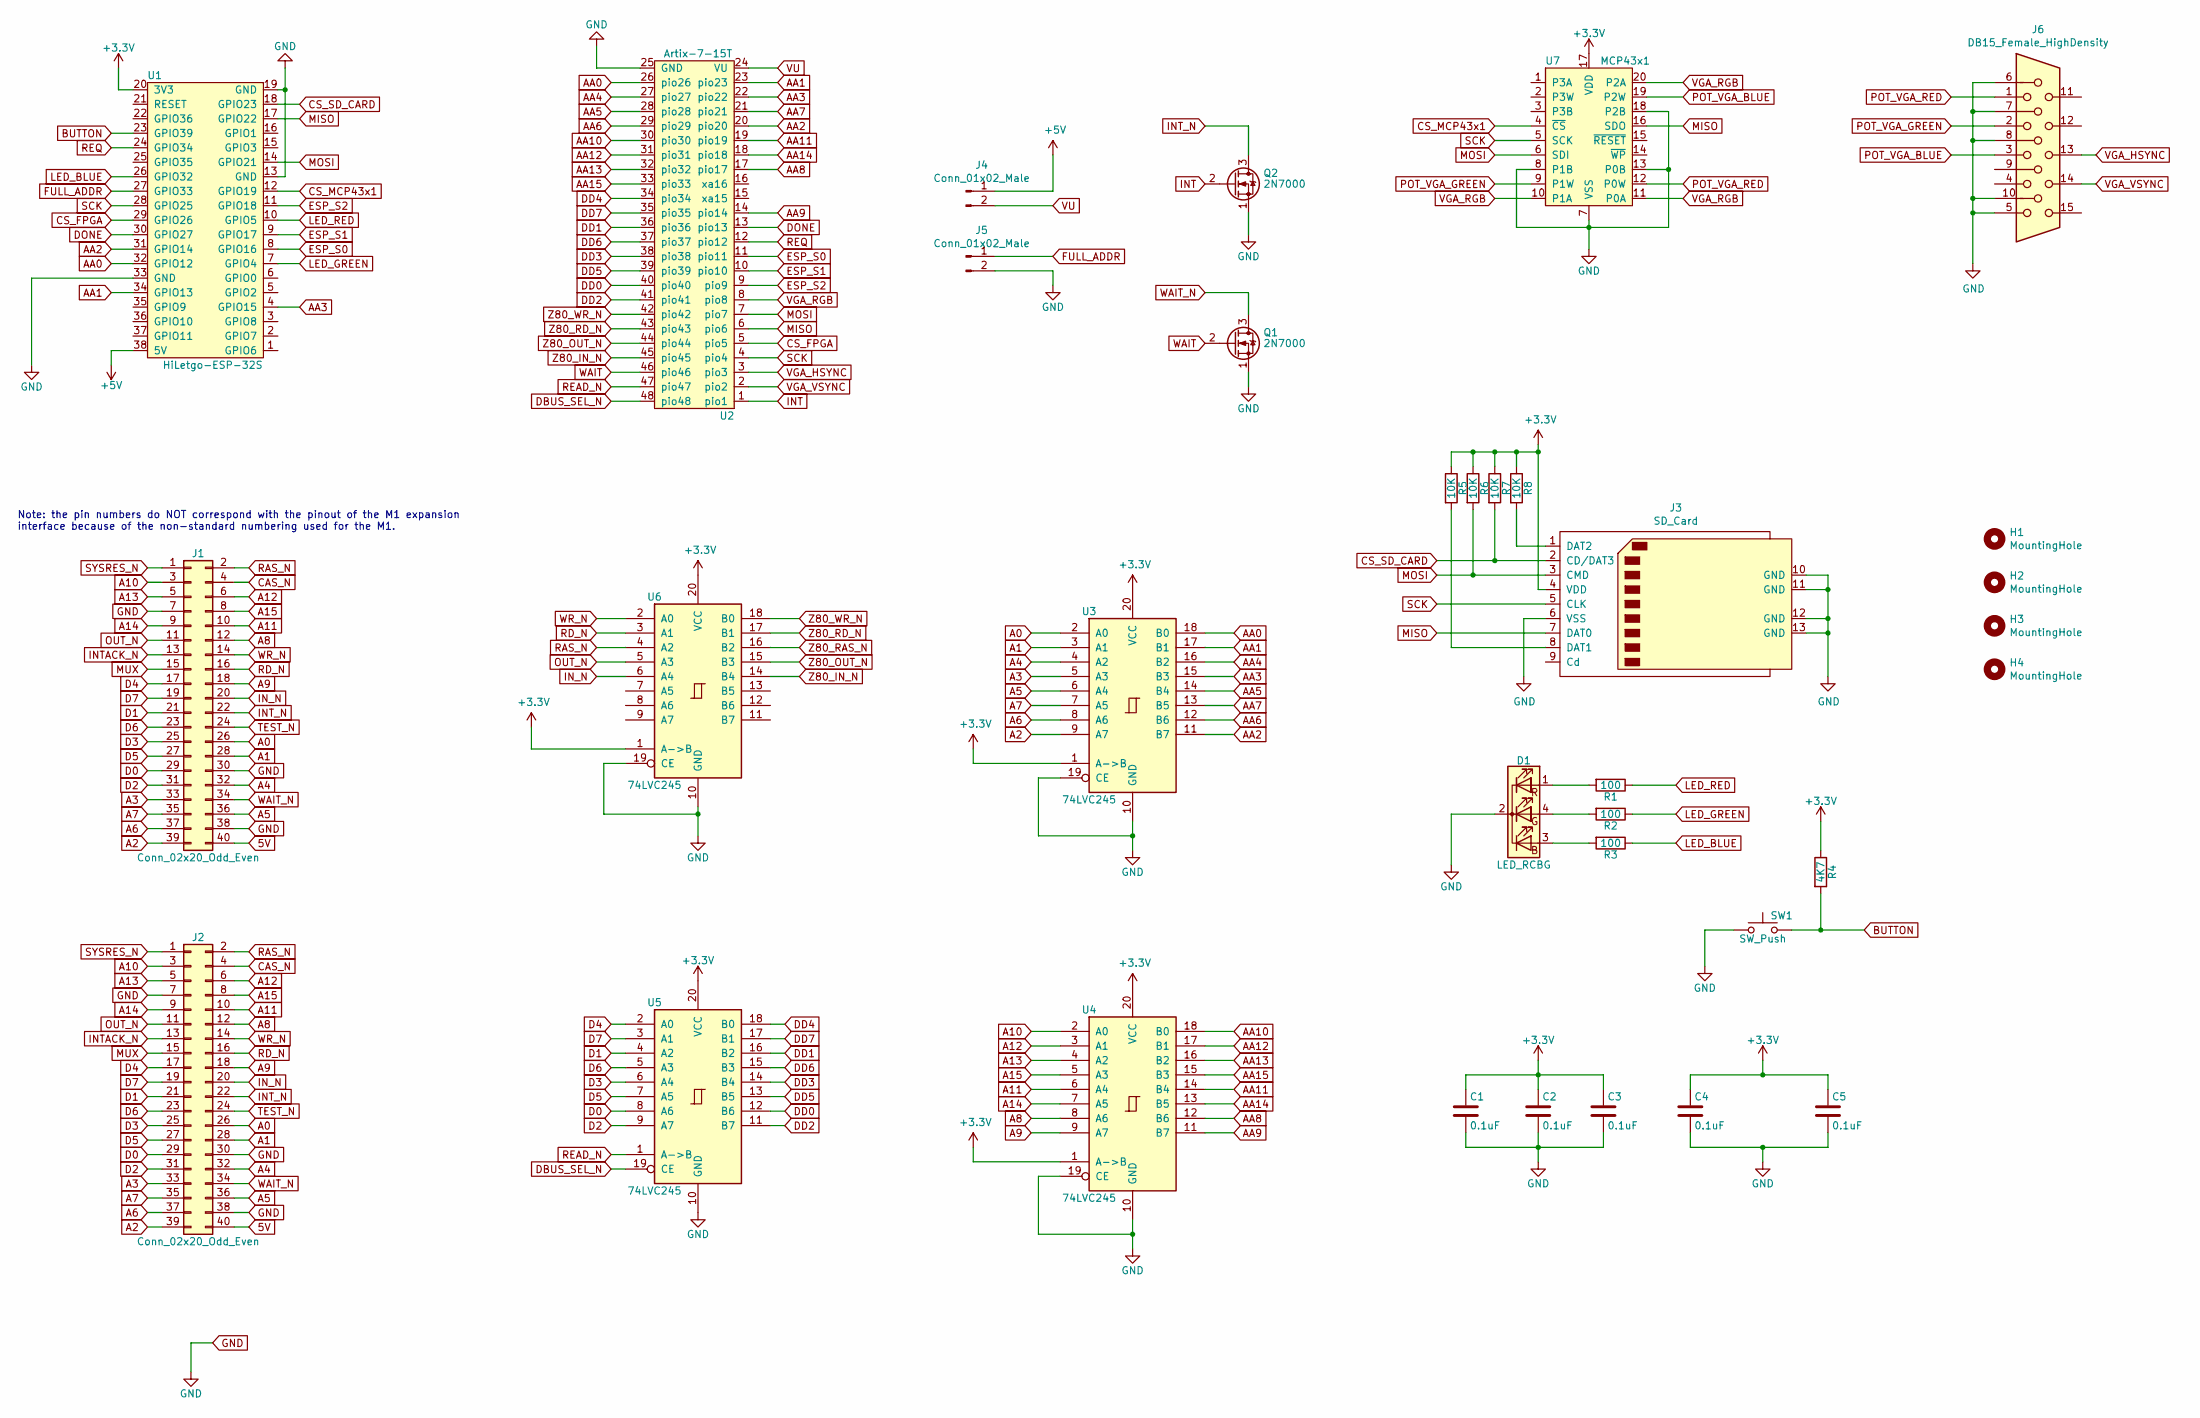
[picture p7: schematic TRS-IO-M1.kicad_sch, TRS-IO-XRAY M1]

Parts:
C1, C2, C3, C4, C5: 0.1uF; C_Disc_D3.0mm_W2.0mm_P2.50mm
D1: LED_RCBG; LED_D5.0mm-4_RGB
H1, H2, H3, H4: MountingHole; MountingHole_3mm_Pad_Via
J1: Conn_02x20_Odd_Even; PinHeader_2x20_P2.54mm_Vertical
J2: Conn_02x20_Odd_Even; TRSEDGE
J3: SD_Card; TFP09-2-12B
J4, J5: Conn_01x02_Male; PinHeader_1x02_P2.54mm_Vertical
J6: DB15_Female_HighDensity; DB_15F-VGA
Q1, Q2: 2N7000; TO-92_Inline
R1, R2, R3: 100; R_Axial_DIN0207_L6.3mm_D2.5mm_P7.62mm_Horizontal
R4: 4K7; R_Axial_DIN0207_L6.3mm_D2.5mm_P7.62mm_Horizontal
R5, R6, R7, R8: 10K; R_Axial_DIN0207_L6.3mm_D2.5mm_P7.62mm_Horizontal
SW1: SW_Push; SW_PUSH_6mm_H9.5mm
U1: HiLetgo-ESP-32S; DIP-38_W22.9mm
U2: Artix-7-15T; DIP-48_600_ELL
U3, U4, U5, U6: 74LVC245; DIP-20_W7.62mm
U7: MCP43x1; TSSOP-20_4.4x6.5mm_P0.65mm

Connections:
5V: J1.40, J2.40
+3V3: C1.1, C2.1, C3.1, C4.1, C5.1, J3.4 (VDD), R4.1, R5.1, R6.1, R7.1, R8.1, U1.20 (3V3), U3.1 (A->B), U3.20 (VCC), U4.1 (A->B), U4.20 (VCC), U5.20 (VCC), U6.1 (A->B), U6.20 (VCC), U7.17 (VDD)
+5V: J4.1, U1.38 (5V)
A0: J1.26, J2.26, U3.2 (A0)
A1: J1.28, J2.28, U3.3 (A1)
A2: J1.39, J2.39, U3.9 (A7)
A3: J1.33, J2.33, U3.5 (A3)
A4: J1.32, J2.32, U3.4 (A2)
A5: J1.36, J2.36, U3.6 (A4)
A6: J1.37, J2.37, U3.8 (A6)
A7: J1.35, J2.35, U3.7 (A5)
A8: J1.12, J2.12, U4.8 (A6)
A9: J1.18, J2.18, U4.9 (A7)
A10: J1.3, J2.3, U4.2 (A0)
A11: J1.10, J2.10, U4.6 (A4)
A12: J1.6, J2.6, U4.3 (A1)
A13: J1.5, J2.5, U4.4 (A2)
A14: J1.9, J2.9, U4.7 (A5)
A15: J1.8, J2.8, U4.5 (A3)
AA0: U1.32 (GPIO12), U2.26 (pio26), U3.18 (B0)
AA1: U1.34 (GPIO13), U2.23 (pio23), U3.17 (B1)
AA2: U1.31 (GPIO14), U2.20 (pio20), U3.11 (B7)
AA3: U1.4 (GPIO15), U2.22 (pio22), U3.15 (B3)
AA4: U2.27 (pio27), U3.16 (B2)
AA5: U2.28 (pio28), U3.14 (B4)
AA6: U2.29 (pio29), U3.12 (B6)
AA7: U2.21 (pio21), U3.13 (B5)
AA8: U2.17 (pio17), U4.12 (B6)
AA9: U2.14 (pio14), U4.11 (B7)
AA10: U2.30 (pio30), U4.18 (B0)
AA11: U2.19 (pio19), U4.14 (B4)
AA12: U2.31 (pio31), U4.17 (B1)
AA13: U2.32 (pio32), U4.16 (B2)
AA14: U2.18 (pio18), U4.13 (B5)
AA15: U2.33 (pio33), U4.15 (B3)
BUTTON: R4.2, SW1.2, U1.23 (GPIO39)
CAS_N: J1.4, J2.4
CS_FPGA: U1.29 (GPIO26), U2.5 (pio5)
CS_MCP43x1: U1.12 (GPIO19), U7.4 (~CS)
CS_SD_CARD: J3.2 (CD/DAT3), R7.2, U1.18 (GPIO23)
D0: J1.29, J2.29, U5.8 (A6)
D1: J1.21, J2.21, U5.4 (A2)
D2: J1.31, J2.31, U5.9 (A7)
D3: J1.25, J2.25, U5.6 (A4)
D4: J1.17, J2.17, U5.2 (A0)
D5: J1.27, J2.27, U5.7 (A5)
D6: J1.23, J2.23, U5.5 (A3)
D7: J1.19, J2.19, U5.3 (A1)
DBUS_SEL_N: U2.48 (pio48), U5.19 (CE)
DD0: U2.40 (pio40), U5.12 (B6)
DD1: U2.36 (pio36), U5.16 (B2)
DD2: U2.41 (pio41), U5.11 (B7)
DD3: U2.38 (pio38), U5.14 (B4)
DD4: U2.34 (pio34), U5.18 (B0)
DD5: U2.39 (pio39), U5.13 (B5)
DD6: U2.37 (pio37), U5.15 (B3)
DD7: U2.35 (pio35), U5.17 (B1)
DONE: U1.30 (GPIO27), U2.13 (pio13)
ESP_S0: U1.8 (GPIO16), U2.11 (pio11)
ESP_S1: U1.9 (GPIO17), U2.10 (pio10)
ESP_S2: U1.11 (GPIO18), U2.9 (pio9)
FULL_ADDR: J5.1, U1.27 (GPIO33)
GND: C1.2, C2.2, C3.2, C4.2, C5.2, D1.2 (K), J1.7, J1.30, J1.38, J2.7, J2.30, J2.38, J3.6 (VSS), J3.10 (GND), J3.11 (GND), J3.12 (GND), J3.13 (GND), J5.2, J6.5, J6.6, J6.7, J6.8, J6.10, Q1.1 (S), Q2.1 (S), SW1.1, U1.13 (GND), U1.19 (GND), U1.33 (GND), U2.25 (GND), U3.10 (GND), U3.19 (CE), U4.10 (GND), U4.19 (CE), U5.10 (GND), U6.10 (GND), U6.19 (CE), U7.7 (VSS), U7.8 (P1B), U7.13 (P0B), U7.18 (P2B)
INT: Q2.2 (G), U2.1 (pio1)
INTACK_N: J1.13, J2.13
INT_N: J1.22, J2.22, Q2.3 (D)
IN_N: J1.20, J2.20, U6.6 (A4)
LED_BLUE: R3.1, U1.26 (GPIO32)
LED_GREEN: R2.1, U1.7 (GPIO4)
LED_RED: R1.1, U1.10 (GPIO5)
MISO: J3.7 (DAT0), U1.17 (GPIO22), U2.6 (pio6), U7.16 (SDO)
MOSI: J3.3 (CMD), R6.2, U1.14 (GPIO21), U2.7 (pio7), U7.6 (SDI)
MUX: J1.15, J2.15
unnamed: D1.1 (RA), R1.2
unnamed: D1.3 (BA), R3.2
unnamed: D1.4 (GA), R2.2
unnamed: J3.1 (DAT2), R8.2
unnamed: J3.8 (DAT1), R5.2
OUT_N: J1.11, J2.11, U6.5 (A3)
POT_VGA_BLUE: J6.3, U7.19 (P2W)
POT_VGA_GREEN: J6.2, U7.9 (P1W)
POT_VGA_RED: J6.1, U7.12 (P0W)
RAS_N: J1.2, J2.2, U6.4 (A2)
RD_N: J1.16, J2.16, U6.3 (A1)
READ_N: U2.47 (pio47), U5.1 (A->B)
REQ: U1.24 (GPIO34), U2.12 (pio12)
SCK: J3.5 (CLK), U1.28 (GPIO25), U2.4 (pio4), U7.5 (SCK)
SYSRES_N: J1.1, J2.1
TEST_N: J1.24, J2.24
VGA_HSYNC: J6.13, U2.3 (pio3)
VGA_RGB: U2.8 (pio8), U7.10 (P1A), U7.11 (P0A), U7.20 (P2A)
VGA_VSYNC: J6.14, U2.2 (pio2)
VU: J4.2, U2.24 (VU)
WAIT: Q1.2 (G), U2.46 (pio46)
WAIT_N: J1.34, J2.34, Q1.3 (D)
WR_N: J1.14, J2.14, U6.2 (A0)
Z80_IN_N: U2.45 (pio45), U6.14 (B4)
Z80_OUT_N: U2.44 (pio44), U6.15 (B3)
Z80_RAS_N: U6.16 (B2)
Z80_RD_N: U2.43 (pio43), U6.17 (B1)
Z80_WR_N: U2.42 (pio42), U6.18 (B0)

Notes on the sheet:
Note: the pin numbers do NOT correspond with the pinout of the M1 expansion interface because of the non-standard numbering used for the M1.

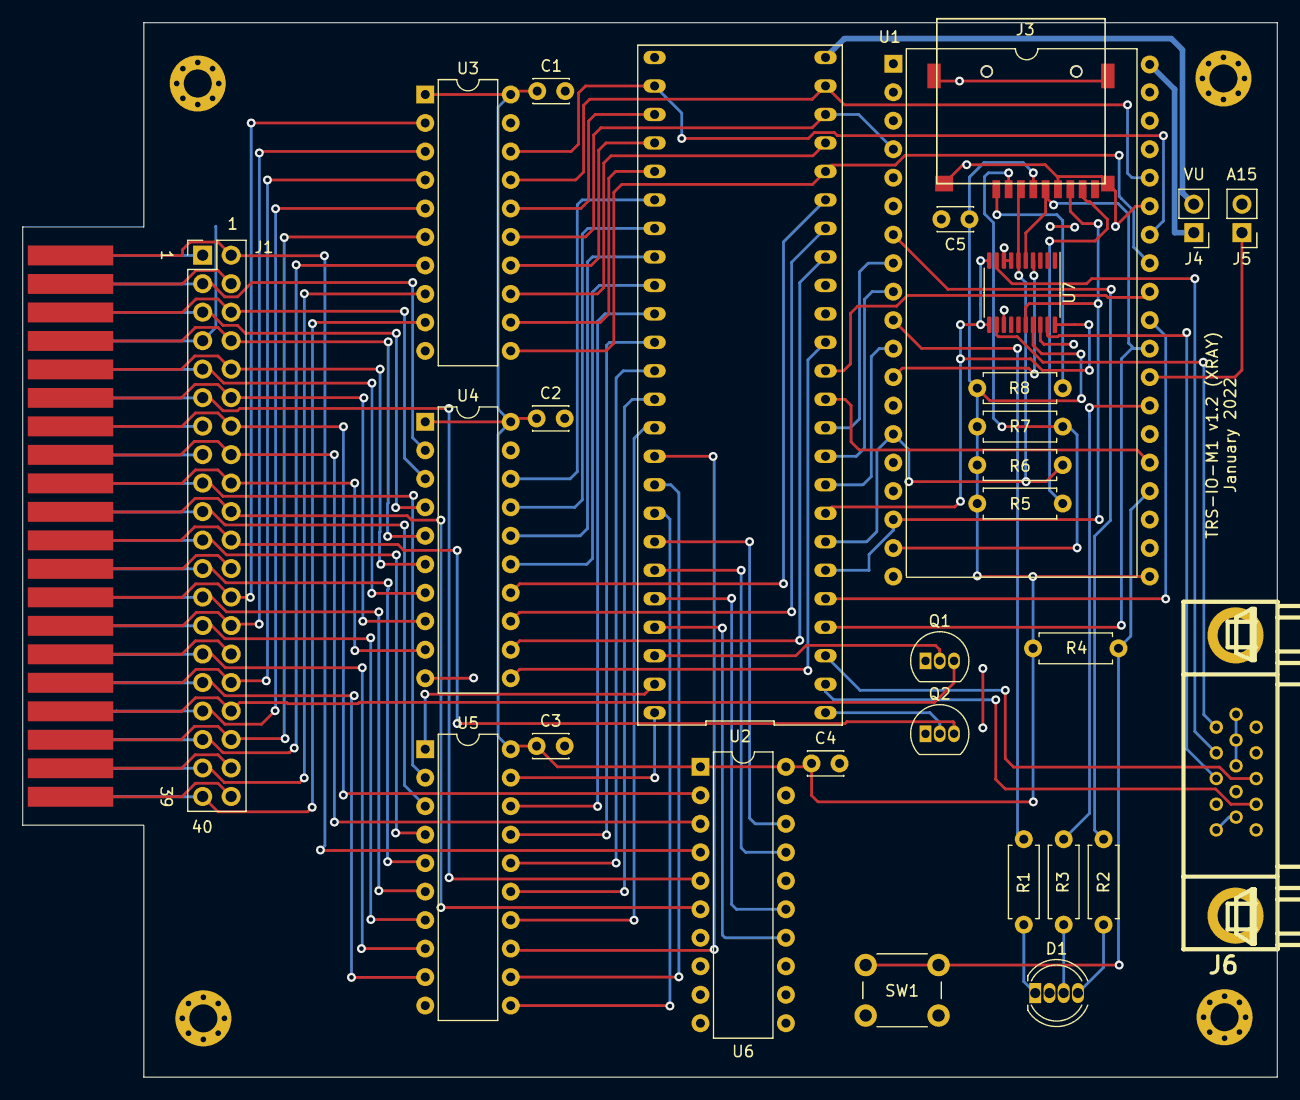
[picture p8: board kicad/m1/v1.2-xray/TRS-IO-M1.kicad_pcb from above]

Board: 2 copper layers, 111.9 x 94.0 mm, 34 parts (0 on the bottom side), 100 nets.

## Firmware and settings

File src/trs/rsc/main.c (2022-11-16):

#include "retrostore.h"
#include "load.h"
#include <trs-lib.h>

#define BOOT_LOADER_ADDR 0x4300
#include "../loader/cmd/loader_cmd.c"


static void copy_boot_loader()
{
  int i;
  uint8_t* p = (uint8_t*) BOOT_LOADER_ADDR;
  for (i = 0; i < loader_cmd_bin_len; i++) {
    *p++ = loader_cmd_bin[i];
  }
}

void load_cmd(uint16_t id) {
  __asm
    pop bc
    pop hl
    jp BOOT_LOADER_ADDR + 3
  __endasm;
}

static void download_and_run(int idx)
{
  wnd_popup("Downloading...");
  copy_boot_loader();
  load_cmd(idx);
}

static uint8_t check() {
  static bool first_time = true;
  uint8_t status;
  uint16_t version;
  
  set_screen_to_foreground();
  if (first_time) {
    wnd_popup("Scanning...");
  }
  first_time = false;

  status = trs_io_status();

  if (status == TRS_IO_STATUS_NO_TRS_IO) {
    wnd_popup("No TRS-IO card present!");
    while(1);
  }

  get_retrostore_version(&version);
  if ((version >> 8) != RS_CLIENT_VERSION_MAJOR) {
    wnd_popup("Incompatible RetroStore card version!");
    while(1);
  }

  //set_screen_to_background();
  return status;
}
  
  
#define MENU_BROWSE 0
#define MENU_SEARCH 1
#define MENU_LOAD 2
#define MENU_WIFI 3
#define MENU_HELP 4
#define MENU_ABOUT 5
#define MENU_EXIT 6

static menu_item_t main_menu_items[] = {
  MENU_ITEM(MENU_BROWSE, "Browse RetroStore"),
  MENU_ITEM(MENU_SEARCH, "Search RetroStore"),
  MENU_ITEM(MENU_WIFI, "Configure WiFi"),
  MENU_ITEM(MENU_HELP, "Help"),
  MENU_ITEM(MENU_ABOUT, "About"),
  MENU_ITEM(MENU_EXIT, "Exit"),
  MENU_ITEM_END
};

static menu_t main_menu = {
  .title = "RetroStore",
  .items = main_menu_items
};


static menu_item_t main_menu_with_xray_items[] = {
  MENU_ITEM(MENU_BROWSE, "Browse RetroStore"),
  MENU_ITEM(MENU_SEARCH, "Search RetroStore"),
  MENU_ITEM(MENU_LOAD, "Load XRAY state"),
  MENU_ITEM(MENU_WIFI, "Configure WiFi"),
  MENU_ITEM(MENU_HELP, "Help"),
  MENU_ITEM(MENU_ABOUT, "About"),
  MENU_ITEM(MENU_EXIT, "Exit"),
  MENU_ITEM_END
};

static menu_t main_menu_with_xray = {
  .title = "RetroStore",
  .items = main_menu_with_xray_items
};


static menu_item_t main_menu_wifi_not_needed_items[] = {
  MENU_ITEM(MENU_BROWSE, "Browse RetroStore"),
  MENU_ITEM(MENU_SEARCH, "Search RetroStore"),
  MENU_ITEM(MENU_HELP, "Help"),
  MENU_ITEM(MENU_ABOUT, "About"),
  MENU_ITEM(MENU_EXIT, "Exit"),
  MENU_ITEM_END
};

static menu_t main_menu_wifi_not_needed = {
  .title = "RetroStore",
  .items = main_menu_wifi_not_needed_items
};


static menu_item_t main_menu_not_connected_items[] = {
  MENU_ITEM(MENU_WIFI, "Configure WiFi"),
  MENU_ITEM(MENU_HELP, "Help"),
  MENU_ITEM(MENU_ABOUT, "About"),
  MENU_ITEM(MENU_EXIT, "Exit"),
  MENU_ITEM_END
};

static menu_t main_menu_not_connected = {
  .title = "Offline",
  .items = main_menu_not_connected_items
};


static window_t wnd;

int main() {
  int idx;
  bool show_from_left = false;
  menu_t* the_menu;
  uint8_t status;
  
  set_m3_mem_map();

  init_trs_lib();
  
  init_window(&wnd, 0, 0, 0, 0);

  while (true) {
    switch (check()) {
    case RS_STATUS_WIFI_NOT_NEEDED:
      the_menu = &main_menu_wifi_not_needed;
      break;
    case RS_STATUS_WIFI_CONNECTED:
      if (has_xray_support()) {
        the_menu = &main_menu_with_xray;
      } else {
        the_menu = &main_menu;
      }
      break;
    default:
      the_menu = &main_menu_not_connected;
      break;
    }
  
    status = menu(the_menu, show_from_left, true);
    if (status == MENU_ABORT || status == MENU_EXIT) {
      break;
    }
    switch (status) {
    case MENU_BROWSE:
      wnd_popup("Loading...");
      idx = browse_retrostore(&wnd);
      if (idx == LIST_ABORT) {
        break;
      }
      download_and_run(idx);
      break;
    case MENU_SEARCH:
      idx = search_retrostore(&wnd);
      if (idx == LIST_ABORT) {
        break;
      }
      download_and_run(idx);
      break;
    case MENU_LOAD:
      load_xray_state();
      break;
    case MENU_WIFI:
      configure_wifi();
      break;
    case MENU_HELP:
      help();
      break;
    case MENU_ABOUT:
      about();
      break;
    }
    show_from_left = true;
  }

  exit_trs_lib();

  return 0;
}

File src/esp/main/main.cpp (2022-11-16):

#include "io.h"
#include "led.h"
#include "button.h"
#include "wifi.h"
#include "ota.h"
#include "storage.h"
#include "event.h"
#include "esp_event.h"

#include "retrostore.h"
#include "backend.h"
#include "trs-io.h"
#include "trs-fs.h"
#include "spi.h"


extern "C" {

void app_main(void)
{
  init_events();
  init_trs_io();
  init_led();
  init_button();
  init_storage();

  if (is_button_pressed()) {
#ifdef TRS_IO_BUTTON_ONLY_AT_STARTUP
    storage_erase();
#else
    switch_to_factory();
#endif
  }
  
  init_ota();
  init_spi();
  init_trs_fs_posix();
  init_wifi();
  init_io();

  vTaskDelete(NULL);
}

} // extern "C"

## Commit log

2022-11-12 Changes from fork and my local stuff
    [TRS-IO-M1-B_Cu.gbr, TRS-IO-M1-B_Mask.gbr, TRS-IO-M1-B_SilkS.gbr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]
2022-11-16 Revert "Changes from fork and my local stuff"
    This reverts commit 389a2e327e33277d89ec96be275a46e34e0f8076.
    [TRS-IO-M1-B_Cu.gbr, TRS-IO-M1-B_Mask.gbr, TRS-IO-M1-B_SilkS.gbr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]
2022-11-16 Changes md5 dup issue
    [mongoose.h]
2023-02-14 Branch reverted to just before combining spi and io since model 1 sd card without fpga had been removed in tip. Will have to cherry pick commits going forward from remote.
